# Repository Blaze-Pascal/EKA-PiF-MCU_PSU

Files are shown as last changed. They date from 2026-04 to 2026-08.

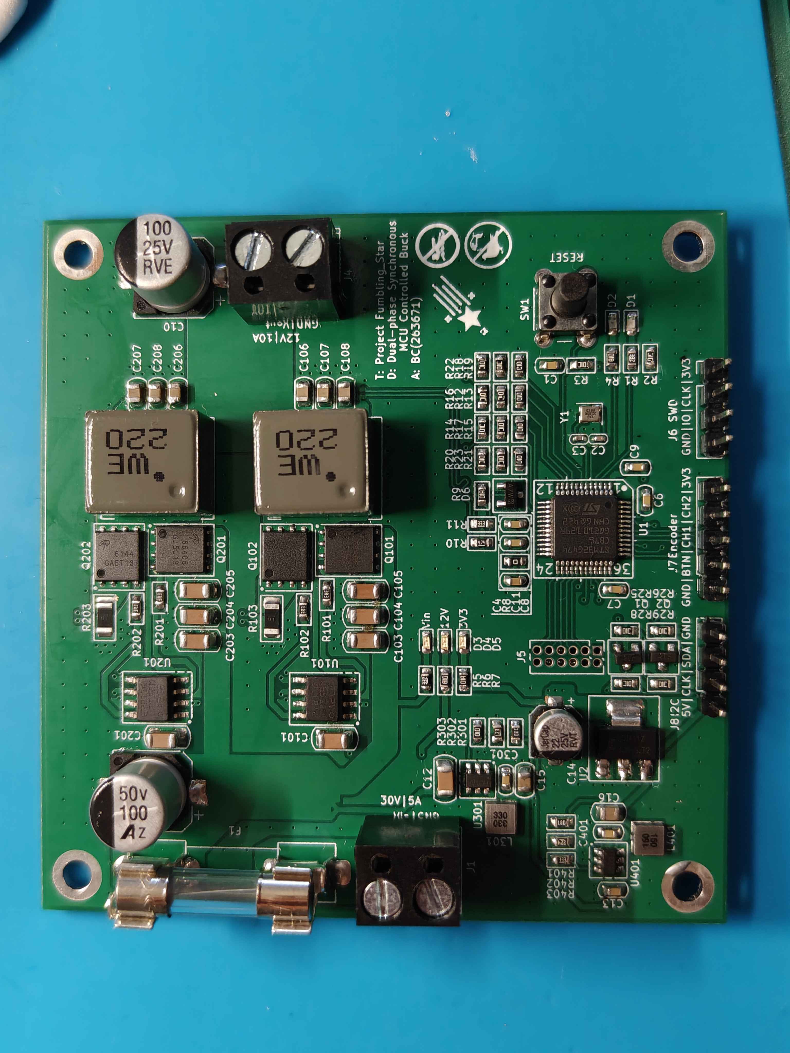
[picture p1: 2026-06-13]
IMG20260607164735.jpg

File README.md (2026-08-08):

# 2-Phase Synchronous Digitally Controlled Buck Converter

Hardware Setup

## Project Overview

**Goal:** Build a multi-phase, MCU-controlled high-power buck converter to act as a current amplifier for a linear lab power supply (30V/5A) at lower voltages.

**Project Scope:**
- **Custom Hardware:** 4-layer power stage and control circuitry designed in KiCad with focus on EMI mitigation. Switching at 250 kHz, designed for 10A at 12V output.
- **Advanced MCU Control:** Firmware written in C (STM32 HAL) for the STM32G474, utilizing a software-defined voltage loop (via FMAC), a pure-hardware current protection loop, and hardware encoder UI integration.

---

## System Architecture

System Schematic Block Diagram

The system is split into two primary domains: the digital control stage, centered around the STM32G474's advanced power-control peripherals, and the power stage, featuring dedicated gate drivers and power MOSFETs.

---

## Hardware Details

### The Power Stage

Power stage

The power stage consists of two identical, interleaved synchronous buck topologies:
- **Gate Drivers:** UCC27211A drivers were selected for their 30V bootstrap tolerance, high 4A peak drive current, and discrete inputs, which allow for precise dead-time insertion directly from the MCU's HRTIM.
- **MOSFETs:** Two different Alpha & Omega DFN-8 MOSFETs are utilized to optimize the specific roles of the buck topology. The AONS66406 is used on the high side for its lower gate charge (faster switching, lower switching losses), while the AON6144 is used on the low side for its lower Rds(on) (better conduction efficiency). 
- **Passives:** The system uses 22µH molded inductors (derated from 8.5A to around 5A). Input capacitance consists of 3x 10µF 50V MLCCs + 100µF electrolytic, while the output utilizes 3x 22µF 25V MLCCs + 100µF electrolytic.

### PCB Layout & EMI Mitigation

PCB Layout Diagram

Great care was taken during the PCB routing phase to minimize radiated and conducted emissions:
- **4-Layer Stackup:** Allows for smaller L1-to-L2 distances, increasing plane coupling and reducing radiated emissions.
- **Strategic Placement:** The MLCC capacitors "hug" the MOSFETs on the input and the inductors on the output to minimize high-frequency current return paths. The slower bulk electrolytic capacitors are placed further out at the input/output terminals.
- **Node Optimization:** The physical copper area of the noisy switching (SW) nodes was kept to an absolute minimum. Molded inductors were chosen specifically to further contain magnetic emissions.
- **Signal Isolation:** Delicate analog feedback signals for the current loops were routed exclusively on the bottom layer to shield them from the noisy power stage on the top layer. They were also routed as differential pairs in order to minimise common mode noise.

### The Digital Stage & UI

Digital stage

The control circuitry relies heavily on the STM32G474's internal mixed-signal capabilities. Additionally, the system features a local user interface: a rotary encoder is connected to a hardware timer in encoder mode, allowing the user to adjust voltage and current setpoints on the fly, which are displayed on an integrated 16x2 LCD.

---

## Control Loop Architecture

<p align="center">
  Voltage loop
  Current loop
</p>

The core of the project is its dual-loop control scheme, leveraging the specific hardware accelerators of the STM32G4 family:

### 1. Software Voltage Control Loop
- **Averaged Sampling:** The High-Resolution Timer (HRTIM) triggers ADC3 to sample the feedback voltage (buffered via an internal OpAmp) at the exact midpoint of the MOSFET's on-time. This effectively averages the signal without requiring software filtering.
- **Hardware Math Acceleration:** The ADC value is sent via DMA directly to the Filter Math Accelerator (FMAC) `WDATA` register, where a Proportional (P) control algorithm is calculated in hardware. 
- **Duty Cycle Update:** Once the FMAC presents the result in the `RDATA` register, it generates an interrupt. The MCU core wakes up, applies corrections for phase current mismatch, and writes the new duty cycle to the HRTIM `CMP1xR` register.

### 2. Hardware Current Control Loop
- **Differential Measurement:** Current is measured via a shunt resistor at the low-side source. The small signal is read differentially for improved noise rejection.
- **Internal Analog Processing:** The voltage is amplified by an internal MCU difference amplifier and immediately fed into a built-in hardware comparator against a threshold set by an internal DAC.
- **Asynchronous Shutdown:** The comparator output is routed directly to the HRTIM external event port. This asynchronous link ensures near-zero latency between an overcurrent event and power stage shutoff, effectively realizing valley current control mode.
- **Blanking Window:** The HRTIM utilizes an internal event blanking window to ignore switching transients, preventing false safety triggers.

---

## Results & Verification

Testing was conducted in progressive stages to ensure system stability and safety:

Test setup

**1. Controller Verification (No Power Stage):** 
Feedback voltages were injected directly into the digital section to validate the software. Interleaving, dead-time insertion, duty cycle adjustment, soft start, current balancing, and overcurrent protection were all verified before high voltage was applied.

**2. Real-World Ripple Testing:** 
With the power stage assembled and hooked to a 25V lab supply, the output voltage ripple was measured at no load.

ripple oscope showcase

The dual-phase interleaved topology yielded a voltage ripple of just 7mVp-p. Compared to single-phase operation (which measured 35mVp-p), interleaving provided an 80% reduction in ripple purely through topology.

**3. Efficiency Analysis:**
The converter was tested across its full operating range using an electronic DC load. 

| Input Volts (V) | Input Current (A) | Output Volts (V) | Output Current (A) | Efficiency (%) |
| :---: | :---: | :---: | :---: | :---: |
| 25.12 | 0.077 | 12.03 | 0.000 | 0.00 |
| 25.12 | 0.218 | 11.91 | 0.299 | 64.82 |
| 24.98 | 0.538 | 11.16 | 0.999 | 82.97 |
| 24.96 | 0.989 | 11.07 | 2.000 | 89.71 |
| 24.90 | 2.110 | 10.92 | 4.500 | 93.60 |
| 24.64 | 3.229 | 10.70 | 7.000 | 94.19 |
| 24.60 | 3.677 | 10.65 | 8.000 | 94.21 |
| 24.56 | 4.573 | 10.55 | 10.000 | 93.95 |

efficiency graph

*Test conditions note: Testing was capped at 25V input (instead of 30V) due to observed ringing at the switching node, which threatened to exceed the transistor voltage ratings.*

---

## Future Improvements

While the current revision serves as a highly successful proof of concept, several areas are targeted for future improvement:

- **Regulator Tuning:** The observed voltage drop under load is due to the implementation of a pure Proportional (P) regulator. A PI regulator caused stability issues in this revision, but with proper parameter tuning, stable operation with minimal offset drop is achievable.
- **Ringing Attenuation:** Adding a snubber circuit or increasing gate resistor values will dampen the switching node ringing. Alternatively, transistors with higher voltage ratings could be used, though at a slight cost to Rds(on) and gate capacitance.
- **Component Optimization:** The passive components and MOSFETs were intentionally over-provisioned for this prototype. A production-ready version would undergo stricter component selection to reduce costs.
- **Software Hardening:** The firmware requires further refinement and exhaustive safety testing to handle edge cases gracefully (e.g., during testing, one phase shut down, and the converter was ultimately saved by the external PSU's overcurrent protection).

---

## Documentation

Comprehensive project documentation is available in the repository (written in Polish, prepared for university coursework in Power Electronics and Digital Signal Controllers):
- **Raport Techniczny:** Initial project considerations and mathematical foundations.
- **Raport Implementacyjny:** Simulated testing and core code fragments.
- **Raport Wdrożeniowy:** Physical implementation and final hardware measurements.
- **Raport Projektowy:** Executive summary of the project lifecycle.

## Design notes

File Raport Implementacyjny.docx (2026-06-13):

Błażej Chodorowski 263671

# Raport Implementacyjny: Oprogramowanie Cyfrowego Sterownika Wielofazowej Przetwornicy Obniżającej

# 1. Wstęp

Celem projektu jest budowa dwufazowej przetwornicy obniżającej napięcie sterowanej w pełni cyfrowo za pomocą mikrokontrolera STM32G4. System realizuje sprzętową, ultraszybką regulację napięcia (Constant Voltage - CV) działającą z częstotliwością 250 kHz oraz sprzętowe ograniczenie prądu (Valley Current Limiting / Constant Current - CC). Dzięki wykorzystaniu akceleratora matematycznego (FMAC), kontrolera DMA oraz zdarzeń sprzętowych (HRTIM External Events), krytyczne pętle sterowania działają niezależnie od głównego rdzenia CPU, pozostawiając zasoby na obsługę interfejsu użytkownika (HMI) oraz funkcji pomocniczych, takich jak programowy Soft-Start czy demokratyczny podział prądów między fazami.

# 2. Architektura Systemu i Sprzętowy Przepływ Danych

Projekt opiera się na dwóch niezależnych pętlach sprzętowych pracujących równolegle:

## 2.1. Główna Pętla Napięciowa (CV - 250 kHz)

Odpowiada za stabilizację napięcia wyjściowego. Przetwarza dane w całości w domenie cyfrowej (format stałoprzecinkowy Q1.15).

## 2.2. Ochronna Pętla Prądowa (Valley Current Limit - CC)

Działa asynchronicznie, z opóźnieniem rzędu ~30-50 ns. Chroni dławiki przed nasyceniem i zapewnia tryb "CC", blokując kolejne cykle kluczowania na podstawie prądu fazy.

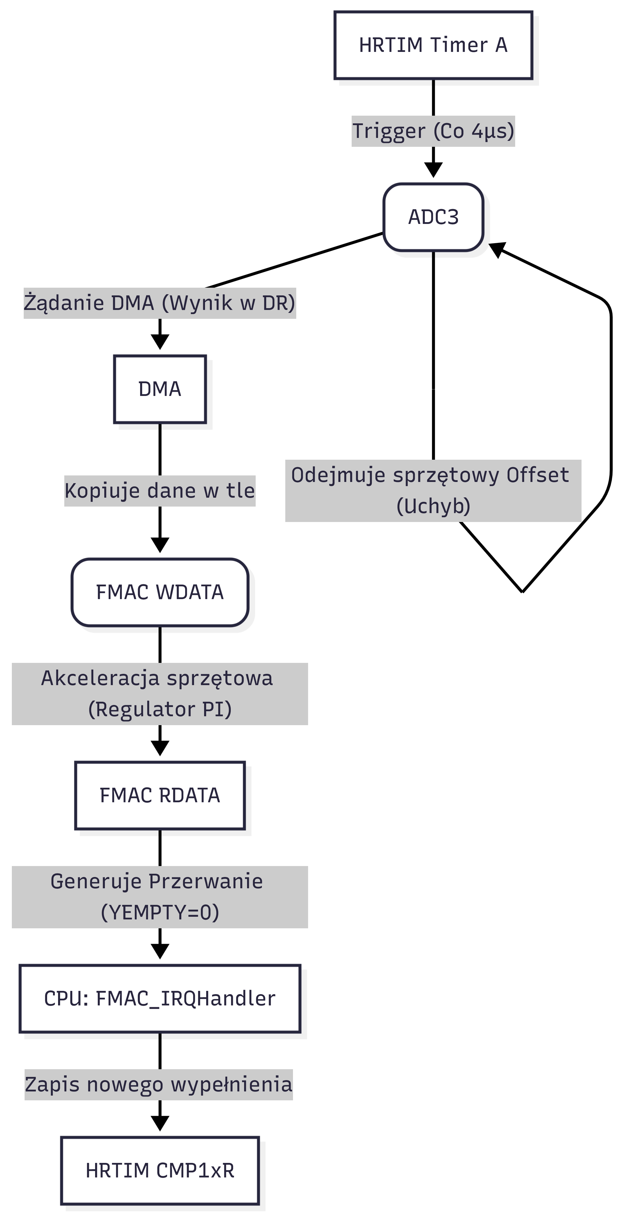
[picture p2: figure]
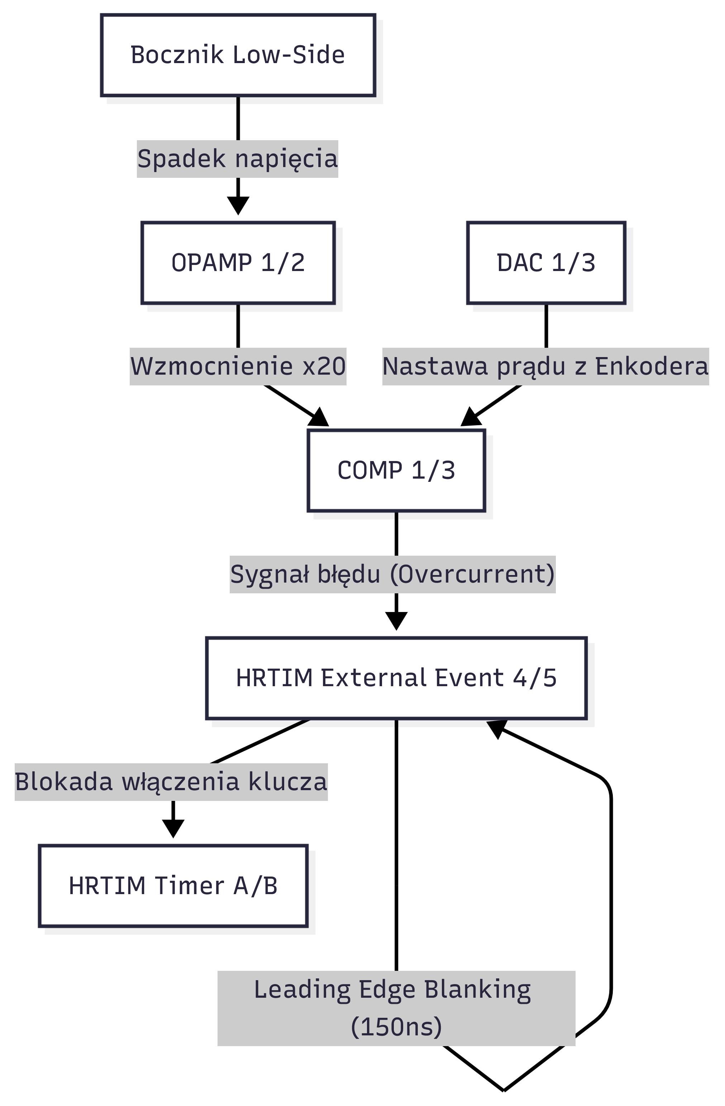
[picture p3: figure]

Rysunek 1 Pętla Napięciowa | Rysunek 2 Pętla Prądowa

# 3. Analiza Kluczowych Modułów Kodu

Poniższe fragmenty kodu ilustrują kluczowe mechanizmy systemu.

## 3.1. Konfiguracja Akceleratora FMAC (Regulator PI)

Akcelerator zastępuje procesor w obliczeniach filtra cyfrowego. Wyliczanie sygnału sterującego odbywa się w pełni sprzętowo.

/* USER CODE BEGIN 2 */

// --- KONFIGURACJA WSPÓŁCZYNNIKÓW FMAC (Regulator PI) ---

FMAC_FilterConfigTypeDef sFmacConfig = {0};

// Wartość 32767 to 1.0 w formacie Q15. Zapewnia idealną pamięć poprzedniego stanu,

// tworząc człon całkujący (I). Dzięki temu uchyb w stanie ustalonym dąży do zera.

int16_t a_coefs[2] = { 32767, 0 };

// Znaki są odwrócone (ujemny b0, dodatni b1), aby zrekompensować ujemne wartości uchybu z ADC

// (kiedy napięcie wyjściowe jest za niskie) i zapewnić ujemne sprzężenie zwrotne pętli.

int16_t b_coefs[3] = { -0x0100, 0x00F0, 0 };

sFmacConfig.pCoeffA = a_coefs;

sFmacConfig.CoeffASize = 2;

sFmacConfig.pCoeffB = b_coefs;

sFmacConfig.CoeffBSize = 3;

// Kanały DMA zasilają FMAC bezpośrednio z ADC, odciążając CPU.

// CPU interweniuje tylko na wyjściu (OutputAccess = IT), aby odebrać gotowy wynik.

sFmacConfig.Filter = FMAC_FUNC_IIR_DIRECT_FORM_1;

sFmacConfig.InputAccess = FMAC_BUFFER_ACCESS_DMA;

sFmacConfig.OutputAccess = FMAC_BUFFER_ACCESS_IT;

HAL_FMAC_FilterConfig(&hfmac, &sFmacConfig);

## 3.2. Obsługa Przerwania FMAC i Current Sharing

Najważniejsza funkcja w systemie. Posiada najwyższy priorytet sprzętowy, stąd zrezygnowano z biblioteki HAL na rzecz bezpośredniego dostępu do rejestrów.

void FMAC_IRQHandler(void)

{

// Weryfikacja gotowości wyniku (YEMPTY zera, oznacza "NIE PUSTY" = gotowy wynik)

if((FMAC->SR & FMAC_SR_YEMPTY) == 0)

{

// Odczyt sprzętowo kasuje żądanie przerwania i odblokowuje pipeline dla kolejnych próbek.

int16_t control_effort_q15 = (int16_t)READ_REG(FMAC->RDATA);

// BEZPIECZNE OKNO AKTUALIZACJI OFFSETU

// Wykonywane tuż po odczycie w czasie przerwania, ponieważ mamy pewność,

// że ADC właśnie zakończyło pomiar i flaga ADSTART = 0.

if (update_offset_flag)

{

ADC3->OFR1 &= ~ADC_OFR1_OFFSET1_EN;

ADC3->OFR1 = (ADC3->OFR1 & ~ADC_OFR1_OFFSET1_Msk) | new_adc_offset;

ADC3->OFR1 |= ADC_OFR1_OFFSET1_EN;

update_offset_flag = 0;

}

// Wyliczenie bazowego wypełnienia z dodaniem limitów nasycenia (Saturacja)

int32_t duty_change = ((int32_t)control_effort_q15 * 21760) >> 15;

int32_t new_ton = pwm_base + duty_change;

if (new_ton < 435) new_ton = 435;

if (new_ton > 10880) new_ton = 10880;

// DEMOKRATYCZNY PODZIAŁ PRĄDU (Average Current Sharing)

// Odczyt ciągły z ADC w locie. Odchyłka w prądach skutkuje nałożeniem delty na fazę 2

// i odjęciem tej samej delty z fazy 1. Dzięki temu całkowita energia układu (suma wypełnień)

// pozostaje stała i główna pętla napięciowa (FMAC) nie traci stabilności.

int32_t current_ph1 = (int32_t)(ADC2->DR);

int32_t current_ph2 = (int32_t)(ADC1->DR);

int32_t balance_effort = (current_ph1 - current_ph2) >> 2; // Proporcjonalny błąd prądu

if (balance_effort > 300) balance_effort = 300;

if (balance_effort < -300) balance_effort = -300;

// Zapis do sprzętowych rejestrów porównawczych z poprawką na prąd faz

HRTIM1->sTimerxRegs[HRTIM_TIMERINDEX_TIMER_A].CMP1xR = new_ton - balance_effort;

HRTIM1->sTimerxRegs[HRTIM_TIMERINDEX_TIMER_B].CMP1xR = (21760 / 2) + new_ton + balance_effort;

// Ucinamy ścieżkę powrotu, nie wchodząc do mało wydajnej obsługi HAL

return;

}

}

## 3.3. Interfejs Użytkownika i Algorytm Soft-Startu

Pętla główna działa asynchronicznie jako system "czasu wolnego" (Low Priority Task). Uniknięto w niej bibliotek blokujących (opóźnień na Systicku), co zapewnia płynność HMI pomimo ogromnej liczby przerwań od akceleratora FMAC w tle.

/* USER CODE BEGIN 3 */

if (HAL_GetTick() - last_update >= 100)

{

last_update = HAL_GetTick();

// 1. ODCZYT ENKODERA (BEZ PRZERWAŃ TIMERA)

// Odczyt sprzętowego licznika zapobiega gubieniu impulsów

int16_t encoder_delta = (int16_t)__HAL_TIM_GET_COUNTER(&htim3);

if (encoder_delta != 0)

{

__HAL_TIM_SET_COUNTER(&htim3, 0);

target_voltage += (float)encoder_delta * 0.1f;

// (Ograniczenia safety: 1.0V do 24.0V)

}

// 2. SOFT-START (Bezpieczna rampa napięcia)

// Zapobiega nasyceniu dławika potężnym prądem inrush, limitując prędkość narastania uchybu w FMAC.

if (current_voltage < target_voltage) {

current_voltage += 0.1f; // +0.1V co 100ms

if (current_voltage > target_voltage) current_voltage = target_voltage;

}

else if (current_voltage > target_voltage) {

current_voltage -= 0.1f;

if (current_voltage < target_voltage) current_voltage = target_voltage;

}

// 3. WYZNACZENIE WARTOŚCI SPRZĘTOWEJ (ADC OFFSET)

// Ograniczenie konwersji zmiennoprzecinkowych zaledwie do jednej iteracji w pętli UI.

float v_pin = current_voltage * (33.0f / 503.0f); // Dzielnik na płytce

uint32_t adc_val = (uint32_t)((v_pin / 2.048f) * 4096.0f);

if (adc_val > 4095) adc_val = 4095;

// Przekazujemy przeliczoną zmienną do wgrania przez bezpieczne okno przerwania.

// Dzięki temu rozwiązujemy problem "Hardware Constraint" zabraniający zapisu do ADSTART=1.

new_adc_offset = adc_val;

update_offset_flag = 1;

// (Kod aktualizujący LCD

}

/* USER CODE END 3 */

# 4. Pomiary weryfikacyjne

W celu weryfikacji poprawności zaimplementowania rozwiązań wykonano szereg pomiarów oscyloskopowych. Ze względu na suboptymalną konstrukcję układu pomiarowego przebiegi wykazują nadmiarowe dzwonienie i przegłos między sygnałami. Zastosowanie poprawnej techniki pomiarowej potwierdziło znaczną redukcję dzwonienia, lecz utrudniało wykonywanie pomiarów.

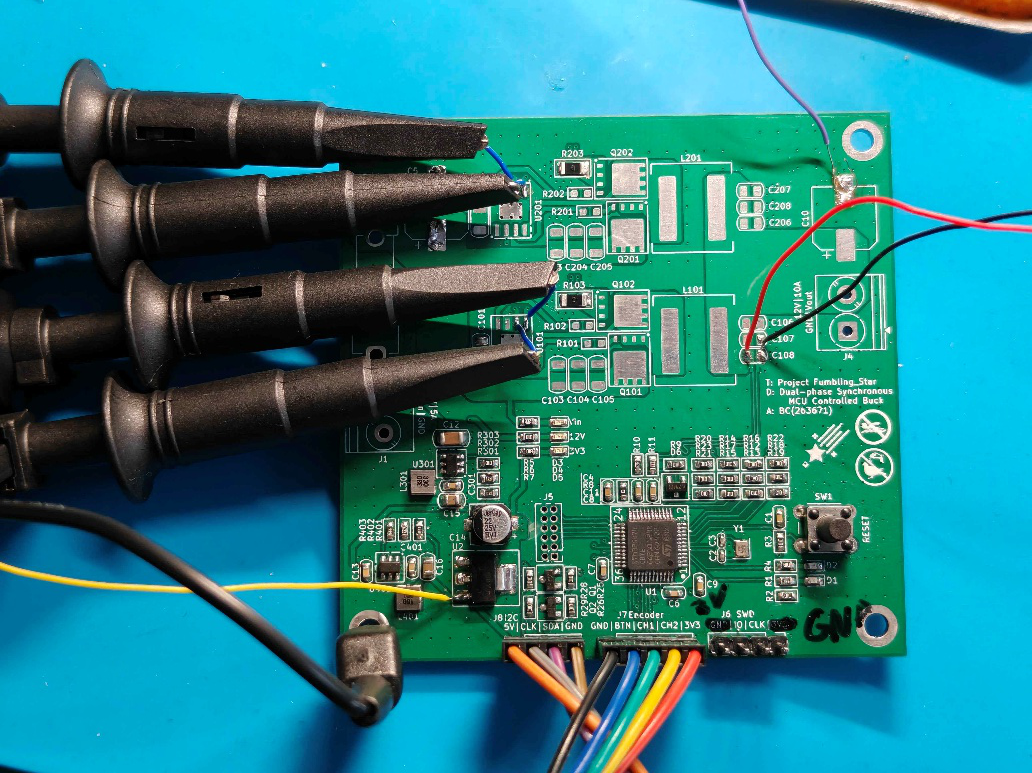
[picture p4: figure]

Rysunek 3 System pomiarowy

## 4.1. Przesunięcie faz

Dokonano pomiarów sygnałów na wyjściach timera HRTIM. Zaobserwowano poprawną nastawę częstotliwości, wypełnienia, przesunięcia fazowego i insercji czasu martwego

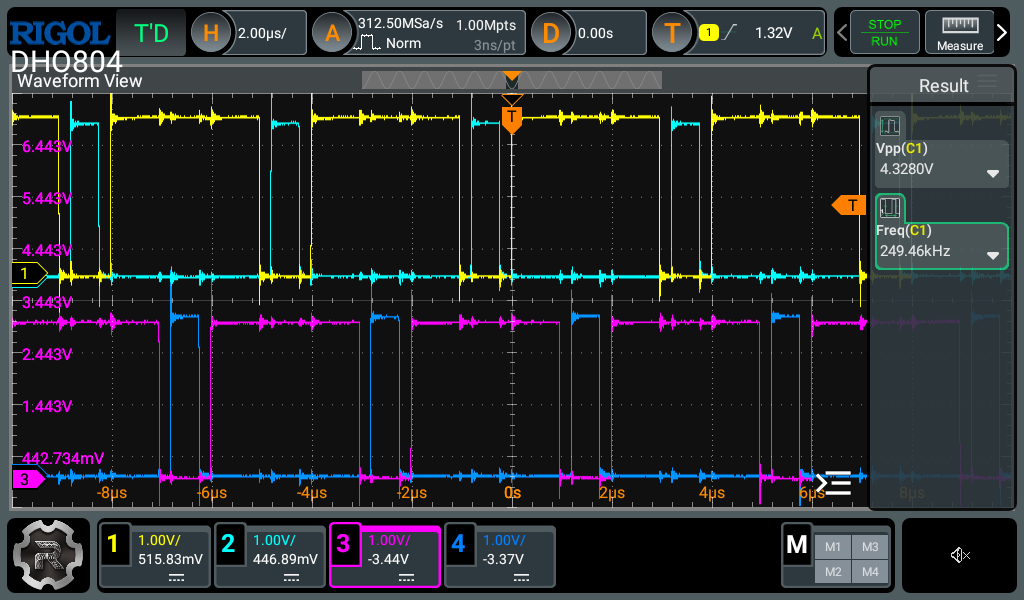
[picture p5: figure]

Rysunek 4 Przebiegi sygnałów na wyjściach HRTIM A i B, weryfikacja przesunięcia fazowego

## 4.2. Czas martwy

Włączono kanały matematyczne wykonujące operację dodawania kanałów dla poszczególnych faz. Zmieniano nastawę programową czasu martwego w celu potwierdzenia poprawnej zmiany i doboru bezpiecznej wartości. Wartość czasu martwego dla kanałów obserwowano poprzez automatyczny pomiar szerokości funkcją -Width. Pomiar zgodny z wyliczeniami dla zegara bloku dead-time w granicach błędu powodowanego dzwonieniem.

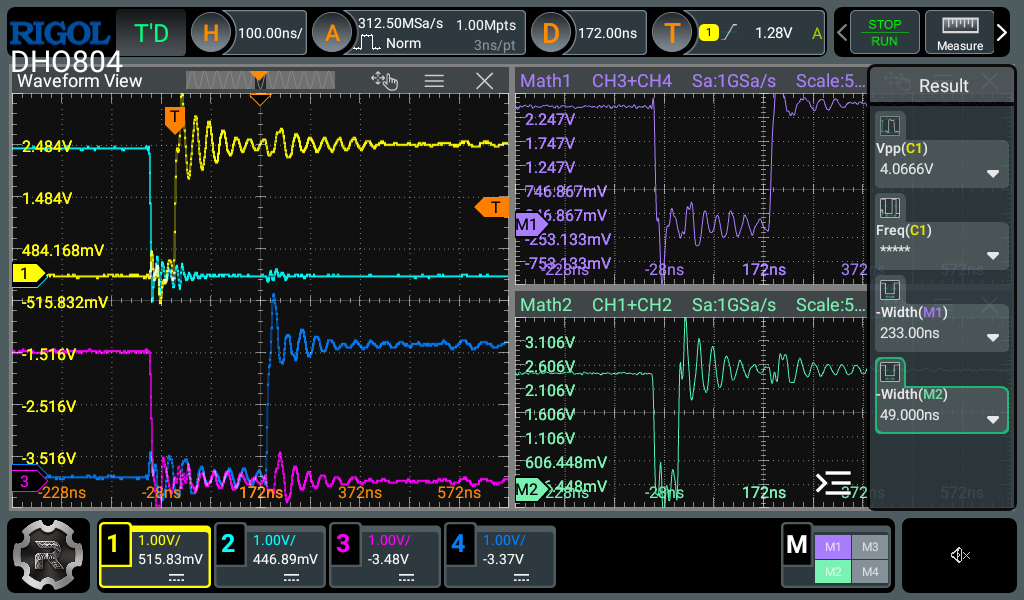
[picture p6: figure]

Rysunek 5 Przebiegi sygnałów na wyjściach HRTIM A i B oraz na kanałach matematycznych, weryfikacja zmiany czasu martwego

## 4.3. Sprzętowe ograniczenie prądowe

Zasilacz laboratoryjny włączono w miejsce pomiaru prądu na boczniku prądowym. Zmieniano nastawę napięcia symulując przepływ prądu przez bocznik zgodnie z zależnością 10mV=1A. Obserwowano zachowanie kanału HRTIM B dla którego symulowano przepływ prądu. Test potwierdził poprawne działanie układu wyłączając klucz górny na czas trwania zdarzenia nadprądowego.

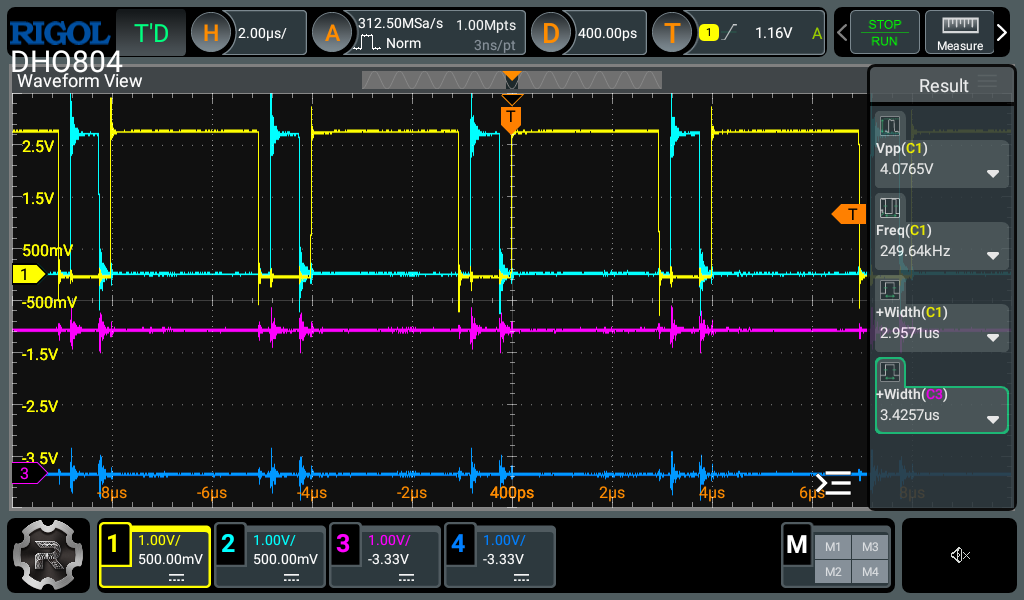
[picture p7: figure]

Rysunek 6 Przebiegi sygnałów na wyjściach HRTIM A i B, kanał B wyłączony przez przekroczenie nastawy prądu

## 4.4. Soft start

Zbadano zachowanie układu podczas rozruchu. W tym celu nastawiono bardzo szeroką podstawę czasu oscyloskopu i mierzono kilka pierwszych sekund startu. Zaobserwowano płynną, liniową zmianę wypełnienia.

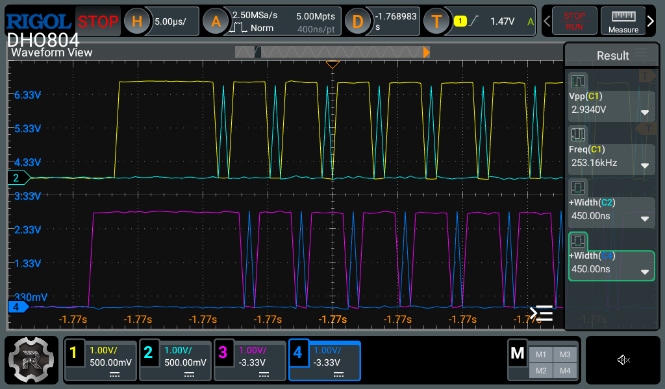
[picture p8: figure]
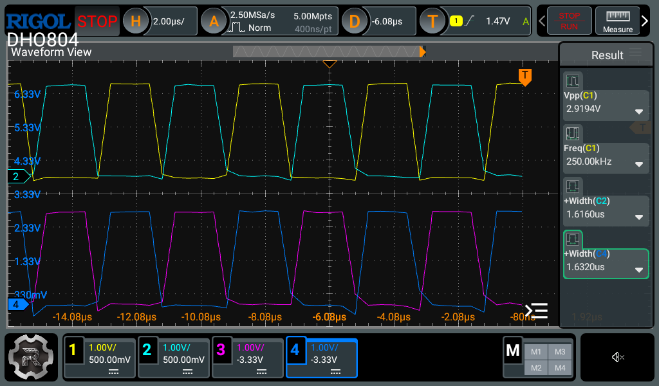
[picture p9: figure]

Rysunek 7 Przebiegi sygnałów na wyjściach HRTIM A i B, moment załączenia HRTIM, wypełnienie minimalne | Rysunek 8 Przebiegi sygnałów na wyjściach HRTIM A i B, około 1,7s później, wypełnienie maksymalne przez odpięte napięciowe sprzężenie zwrotne

## 4.5. Balansowanie prądu faz

Programowo wprowadzono niezbalansowanie prądów faz w celu weryfikacji zmian wypełnienia między fazami. Obserwowano czas załączenia pomiarem +Width dla kanałów 2 i 4 oscyloskopu odpowiadających kluczom high side swoich faz. Zaobserwowano wydłużenie czasu załączenia dla fazy o niższym i skrócenie dla fazy o niższym prądzie.

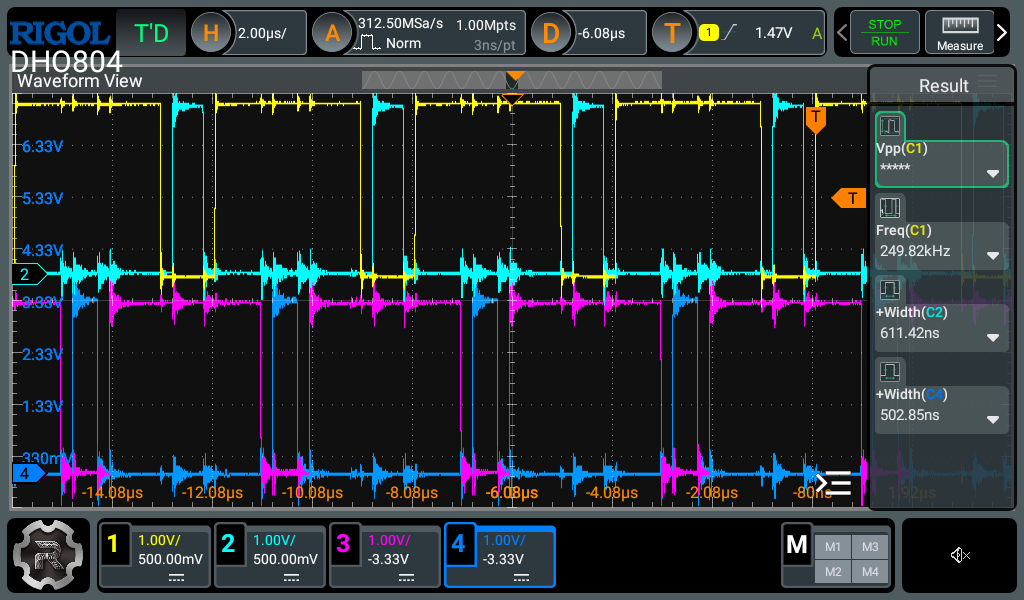
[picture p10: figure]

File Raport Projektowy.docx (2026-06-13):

Błażej Chodorowski 263671

# Raport projektowy

cyfrowo sterowana, Dwufazowa, przetwornica Synchroniczna obniżająca

# 1. Wstęp

Celem projektu było zaprojektowanie, zbudowanie, zaprogramowanie i zbadanie sterowanej cyfrowo dwufazowej przetwornicy synchronicznej obniżającej napięcie. Kluczowe parametry to: napięcie wejściowe 30V, napięcie wyjściowe nastawne, nominalnie 12V, prąd wyjściowy 10A. Projekt oparto na mikrokontrolerze dedykowanym układom mocy STM32G474. Dzięki zastosowaniu zaawansowanych peryferiów takich jak HRTIM i FMAC pełni on rolę cyfrowego kontrolera sygnałów DSC.

# 2. Projekt części sprzętowej

Projekt składa się z głównych bloków hierarchicznych: zasilania pomocniczego, sekcji cyfrowej, dwóch stopni mocy, sekcji feedback. Zdjęcia wnętrz bloków znajdują się w sekcji dodatki.

Sekcje zasilania pomocniczego obniżają napięcie wejściowe w dwóch krokach: Vin->12V dla sterowników bramek i 12V->5V dla zasilania sekcji cyfrowej. 5V trafia na zasilanie wyświetlacza i LDO obniżające do 3.3V dla sekcji mikrokontrolera.

Sekcja mikrokontrolera zawiera w sobie mikrokontroler wraz z elementami do zasilania i taktowania, rezystory dla wbudowanych wzmacniaczy operacyjnych, konwerter stanów logicznych dla komunikacji z wyświetlaczem, złącza enkodera i wyświetlacza.

Stopień mocy zawiera w sobie sterowniki bramek UCC27211D: maksymalne napięcie boost 120V, prąd sink/source 4A, wejścia sterujące TTL, niezależnie sterowanie HI/LO pozwalające na programowy dead-time insertion. Klucze to Alpha&Omega AON6144 o niższym RDSon i AONS66406 o niższym gate charge. Taki dobór powinien minimalizować straty w przetwornicy buck, w której dolny klucz jest załączony dłużej niż górny. Wartości kondensatorów wejściowych, wyjściowych oraz cewek wyliczono ze wzorów podanych w raporcie aplikacyjnym SLVA477B od Texas Instruments. Dodano boczniki mierzące prąd podczas załączenia dolnych kluczy.

Feedback obliczono tak, aby mieścił się w bezpiecznym zakresie dla logiki cyfrowej. Dodatkowo zastosowano ultraszybką diodę zabezpieczającą w celu ochrony przed zbyt wysokim napięciem.

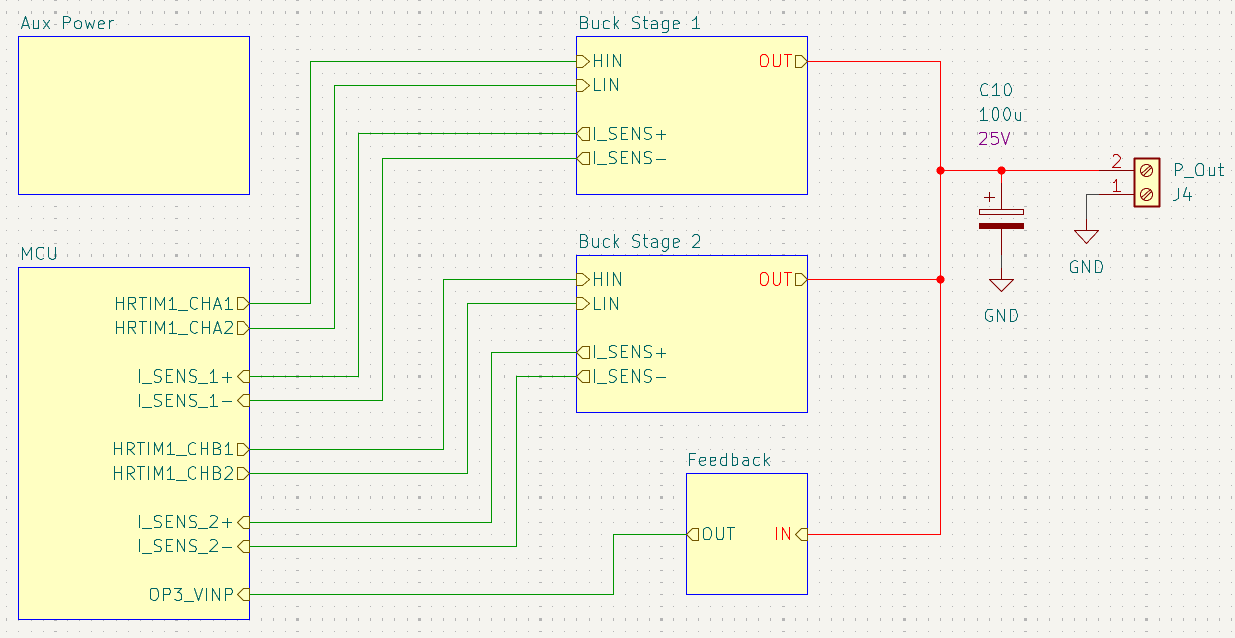
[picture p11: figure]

Rysunek 1 Schemat blokowy części sprzętowej

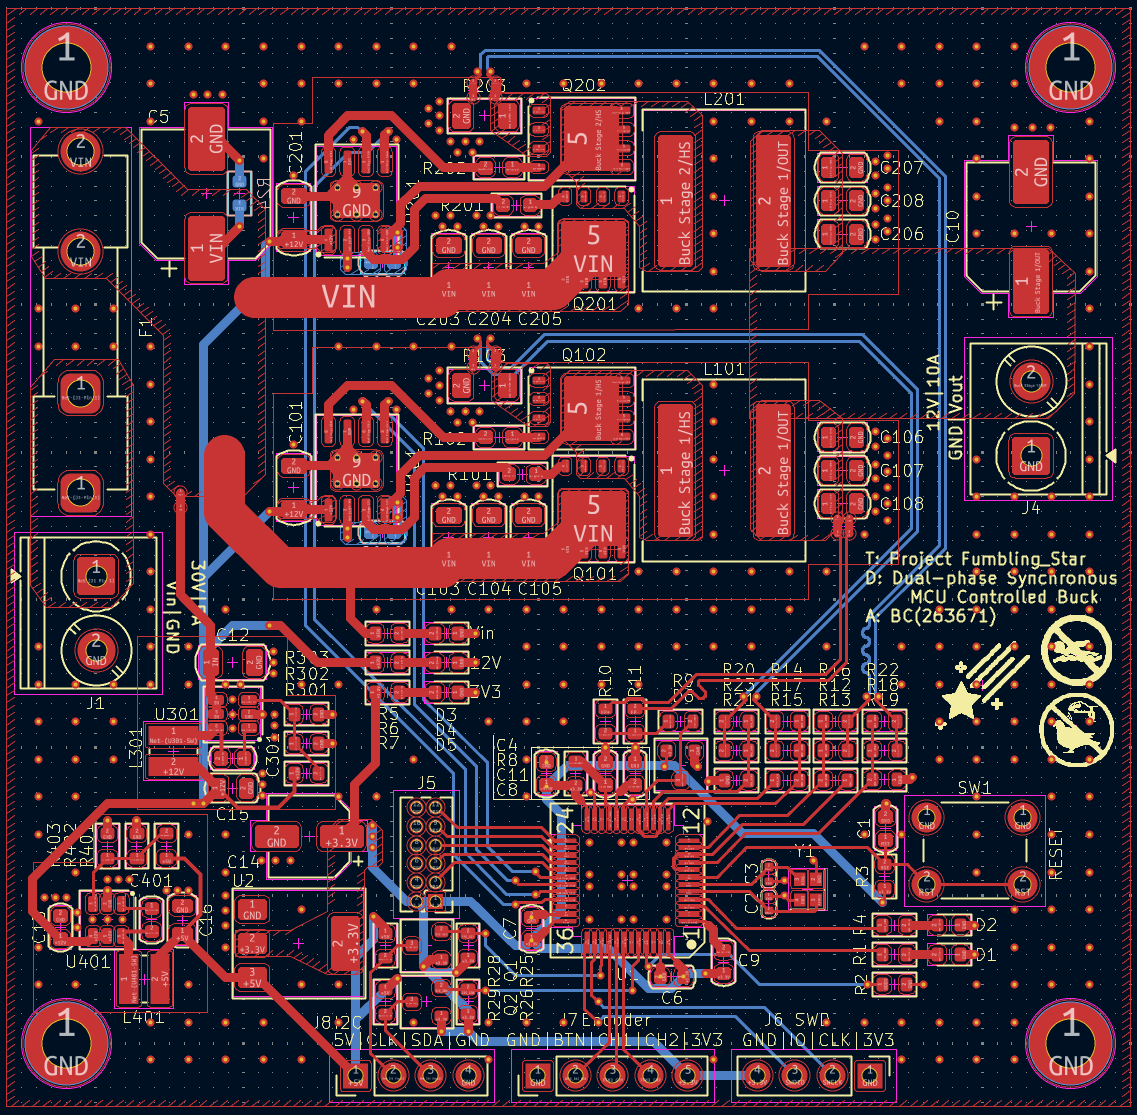
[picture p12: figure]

Rysunek 2 Projekt PCB

# 3. Oprogramowanie mikrokontrolera i peryferia

System wykorzystuje bogatą gammę peryferiów mikrokontrolera STM32G474 do realizacji funkcji DSC. Całość kodu dostępna w repozytorium GitHub projektu: https://github.com/Blaze-Pascal/EKA-PiF-MCU_PSU

Zegar wysokiej rozdzielczości HRTIM służy do sterowania bramkami tranzystorów z częstotliwością 250 kHz. Master Timer generuje przesunięcie fazowe natomiast Timera A i B generują komplementarne przebiegi sterujące. Sprzętowy blok dead-time dodaje czas martwy między kluczami. Dodatkowe poziomy Compare wyzwalają zdarzenia takie jak próbkowanie ADC w połowie załączenia klucza, aby naturalnie uzyskać wartość średnią i zignorować szpilki powstałe podczas przełączania kluczy.

Pomiar prądu realizowany jest poprzez użycie wbudowanych wzmacniaczy operacyjnych w trybie Standalone. Wyprowadzone na piny MCU wzmacniacze zostały następnie połączone do rezystorów tworząc konfigurację wzmacniaczy różnicowych. Pozwala to na wzmocnienie słabego sygnału z boczników do poziomu ADC. Do pomiaru napięcia wzmacniacz został skonfigurowany jako bufor gwarantując wysoką impedancję przetwornikowi i izolując go od dużych wartości rezystancji dzielnika napięciowego. ADC używa wbudowanego źródła napięcia odniesienia co poprawia jego precyzję.

Wyjście wzmacniaczy sygnału prądowego zostało również połączone na płytce z komparatorami pełniącymi rolę sprzętowego ograniczenia prądowego pozwalającego na Valley Current Control. Wzmocniony sygnał jest porównywany z napięciem odniesienia generowanym przez DAC. Jeżeli wartość prądu przekroczy wartość odniesienia sygnał błędu natychmiast trafia na wejścia External Event HRTIM asynchronicznie rozłączając klucz górny do momentu zmniejszenia prądu wyjściowego. Event ma dodatkowo założony Blanking powodujący zignorowanie sygnałów z komparatorów w momencie przełączania kluczy, gdzie może dojść do wystąpienia szpilek prądowych i zarejestrowania zdarzenia false positive.

Pomiar z feedbacku napięciowego trafia na ADC. Po konwersji wartość jest odbierana przez DMA i wysyłana do FMAC – koprocesora matematycznego stworzonego i zoptymalizowanego do liczenia filtrów. Tam zaimplementowano kontroler P obliczający nową wartość wypełnienia dla HRTIM. Wartość jest przekazywana do CPU przez wygenerowanie przerwania i jest następnie dopasowywana do pożądanego zakresu wypełnień (dla poprawnego działania bootstrapu nie można dopuścić do nastawy 100% wypełnienia). Dodatkowo realizowana jest funkcja phase balancing wyrównująca prądy faz na podstawie pomiarów prądu z innych ADC. Po wykonaniu obliczeń, CPU aktualizuje wartości w rejestrach compare HRTIM zmieniając odpowiednia wypełnienie.

Interfejs użytkownika obejmuje wyświetlacz 16x2 sterowany po I2C pokazujący nastawy napięcia i prądu oraz z enkodera połączonego do timera ogólnego przeznaczenia skonfigurowanego w trybie enkodera co zapobiega gubieniu kroków przez enkoder i ogranicza ilość przerwań, które musi obsłużyć procesor.

Zaimplementowano prosty algorytm soft-start, który generuje liniową rampę napięcia zadanego przy starcie przetwornicy. Pętla sprzężenia zwrotnego płynnie podąża za tą wartością, co zapobiega nasyceniu dławików i ogranicza prąd rozruchowy.


Rysunek 3 Pętla napięciowa | Rysunek 4 Pętla prądowa


Rysunek 5 Przebiegi sygnałów na wyjściach HRTIM A i B, weryfikacja przesunięcia fazowego

# 4. Uruchomienie i pomiary

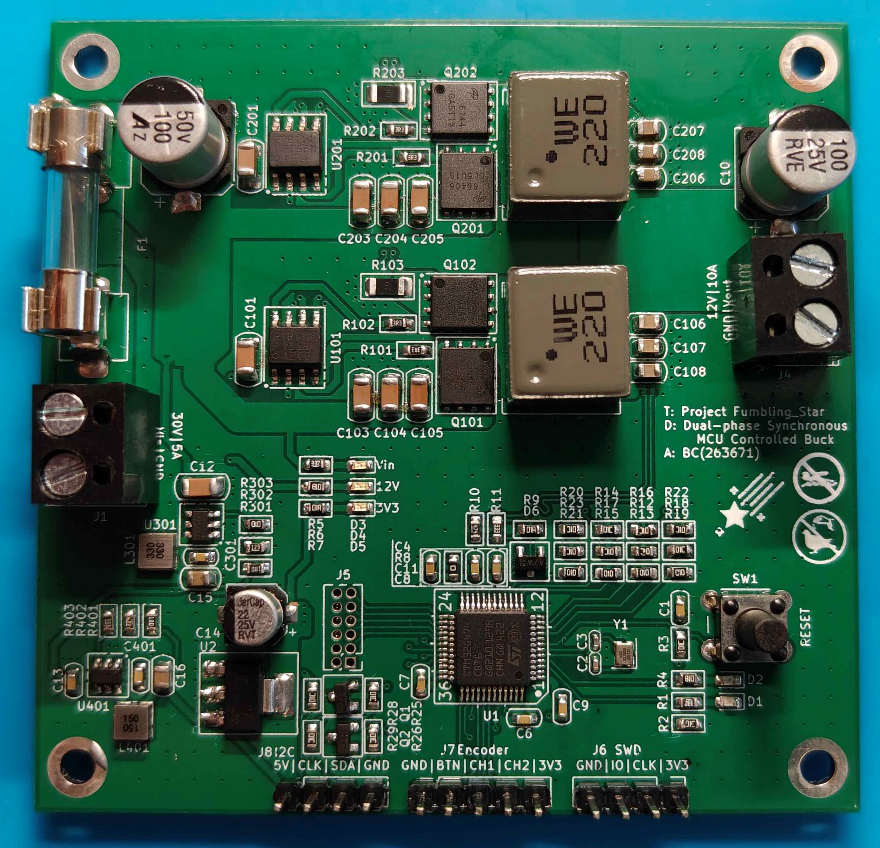
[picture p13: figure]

Rysunek 6 Zbudowany układ

## 4.1. Interleaving i tętnienia wyjściowe

Jedną z zalet konstrukcji wielofazowych jest redukcja tętnień napięcia wyjściowego. Pomiary przeprowadzono sondą oscyloskopową na terminalu wyjściowym stosując sprężynę, aby zminimalizować zakłócenia elektromagnetyczne z otoczenia. Badano amplitudę zakłóceń dla różnych konfiguracji. Pasmo oscyloskopu ograniczone do 20 MHz zgodnie z metodologią pomiaru tętnień zasilaczy.

### 4.1.1. Praca jednofazowa (sonda 10:1, pasmo 20MHz):

Pomiar wykonany bez obciążenia. Tętnienia zmierzone na poziomie ok. 35 mVp-p. Częstotliwość równa częstotliwości pojedynczej fazy: 250 kHz.

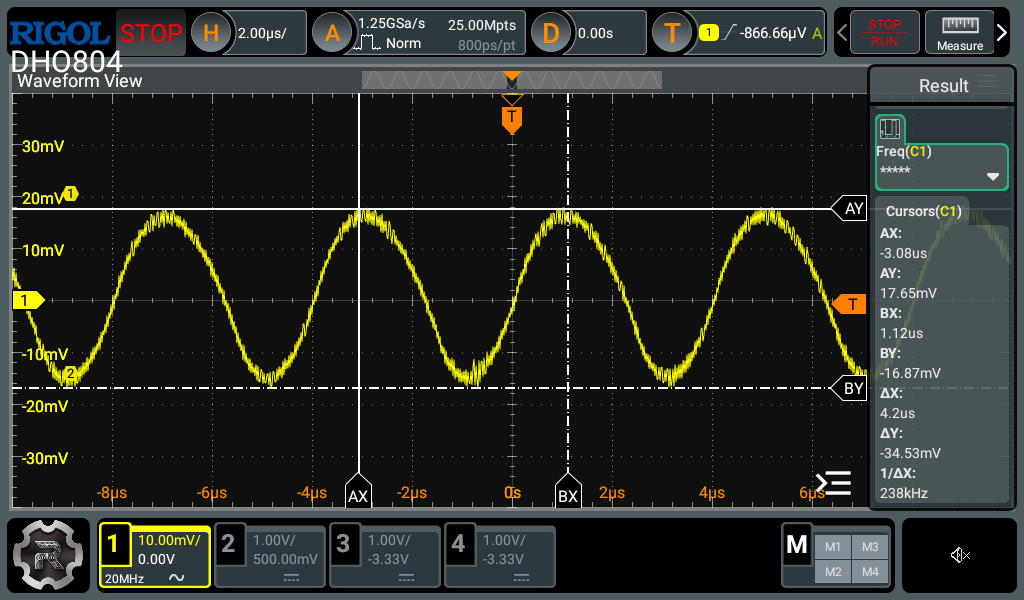
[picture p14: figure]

Rysunek 7 Pomiar tętnień, jedna faza, bez obciążenia

### 4.1.2. Praca dwufazowa z przesunięciem 180° (sonda 1:1, pasmo 20MHz):

Pomiar wykonany bez obciążenia. Tętnienia zmierzone na poziomie ok. 7 mVp-p. Częstotliwość równa częstotliwości dwóch faz: 500 kHz.

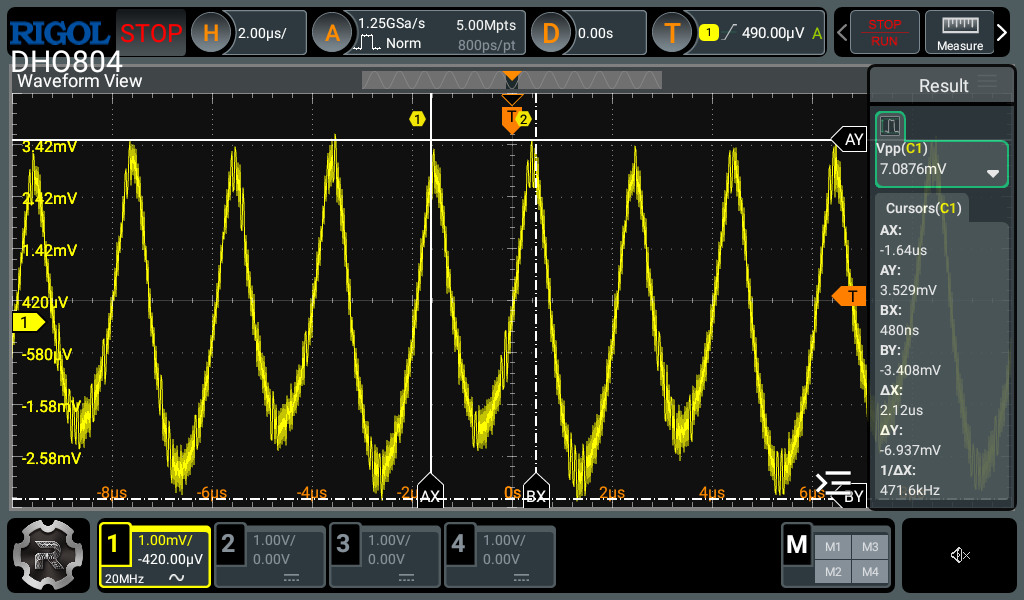
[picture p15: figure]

Rysunek 8 Pomiar tętnień, dwie fazy, bez obciążenia

### 4.1.3. Obciążenie 5A, układ dwufazowy (sonda 1:1, pasmo 20MHz):

Pomiar wykonany przy obciążeniu 5A. Tętnienia bazowe na poziomie 6mVpp (widoczne sporadyczne pakiety szumów otoczenia/zasilacza).

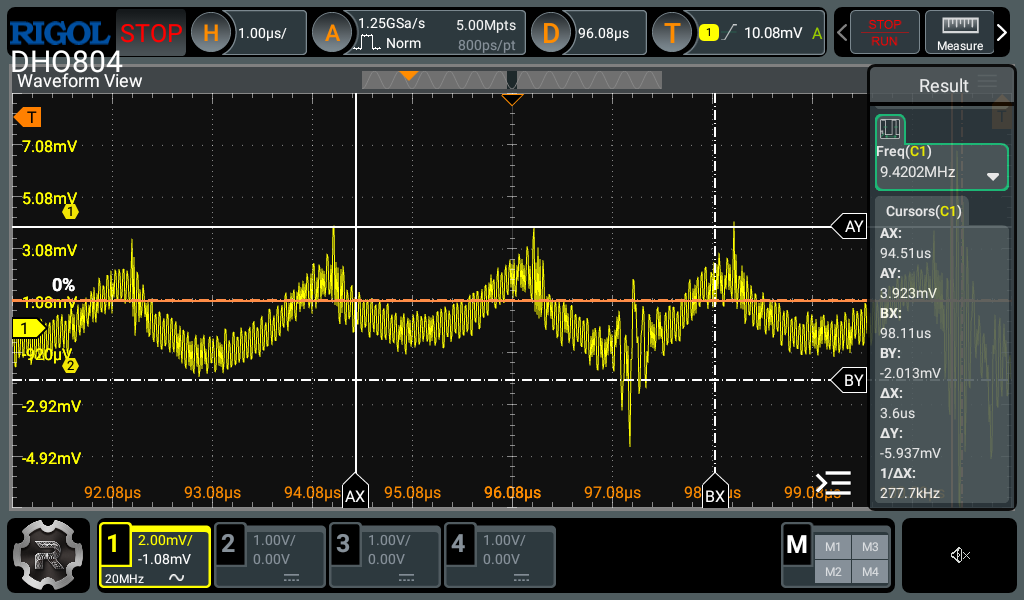
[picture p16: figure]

Rysunek 9 Pomiar tętnień, dwie fazy, obciążenie 5A

Przesunięcie fazowe udowadnia swoją skuteczność. Prądy dławików w węźle sumującym skutecznie znoszą się nawzajem, obniżając amplitudę tętnień napięcia o blisko 80% i podwajając ich częstotliwość, co znacząco odciąża pojemności wyjściowe.

## 4.2. Sprawność energetyczna i odpowiedź pętli sterowania

Zebrano charakterystykę sprawności przetwornicy w zakresie obciążeń od 0A do 10A. W testowanej rewizji oprogramowania aktywny był wyłącznie człon proporcjonalny (P) regulatora.

Tabela 1 Wyniki pomiarów sprawności

Brymen bm2257 | Keysight 34465A [10A] | BKPrecision 8601 | BKPrecision 8601
Uin [V] | Iin [A] | Uout [A] | Iout [A] | n [%]
25.12 | 0.07750 | 12.0301 | 0.000 | 0.00
25.16 | 0.12420 | 11.9954 | 0.099 | 38.00
25.12 | 0.17166 | 11.9501 | 0.199 | 55.15
25.12 | 0.21874 | 11.9122 | 0.299 | 64.82
25.14 | 0.26572 | 11.8791 | 0.399 | 70.95
25.16 | 0.31158 | 11.8018 | 0.499 | 75.12
24.98 | 0.42227 | 11.4065 | 0.748 | 80.89
24.98 | 0.53833 | 11.1680 | 0.999 | 82.97
24.97 | 0.76457 | 11.1149 | 1.499 | 87.27
24.96 | 0.98958 | 11.0797 | 2.000 | 89.71
24.96 | 1.21411 | 11.0465 | 2.500 | 91.13
24.94 | 1.43800 | 11.0143 | 2.999 | 92.10
24.92 | 1.66217 | 10.9850 | 3.500 | 92.82
24.91 | 1.88590 | 10.9564 | 3.999 | 93.27
24.90 | 2.11014 | 10.9291 | 4.500 | 93.60
24.88 | 2.33426 | 10.9020 | 5.000 | 93.86
24.86 | 2.78213 | 10.8480 | 6.000 | 94.11
24.64 | 3.22951 | 10.7074 | 7.000 | 94.19
24.60 | 3.67723 | 10.6532 | 8.000 | 94.21
24.58 | 4.12519 | 10.6006 | 9.000 | 94.09
24.56 | 4.57387 | 10.5534 | 10.000 | 93.95

Rysunek 10 Wykres sprawności w zależności od obciążenia

Punkt maksymalnej sprawności rzędu 94.21% określono dla obciążenia 8 A. Zauważalny spadek napięcia wyjściowego (z 12.03V do 10.55V) przy maksymalnym obciążeniu jest objawem pracy samego członu proporcjonalnego. Układ zatrzymuje się w punkcie równowagi, gdzie zwiększony błąd jest niezbędny do wygenerowania wyższego wypełnienia PWM kompensującego fizyczne spadki napięć na rezystancjach pasożytniczych (cewki, klucze, ścieżki). System sprzętowy działa bez zarzutu, a docelowe usztywnienie charakterystyki wyjściowej zostanie zrealizowane poprzez aktywację członu całkującego (współczynniki dla akceleratora FMAC) w rozwojowej wersji oprogramowania.

## 4.3. Charakterystyka przełączania

Zbadano przebiegi sygnału w węźle przełączającym. Dokonano pomiarów zboczy narastających i opadających oraz dzwonienia. Aby zminimalizować wpływ układu pomiarowego na wyniki wykorzystano sondę w trybie 10:1 minimalizując pojemność i maksymalizując pasmo oraz sprężynę minimalizując indukcyjność pasożytniczą.

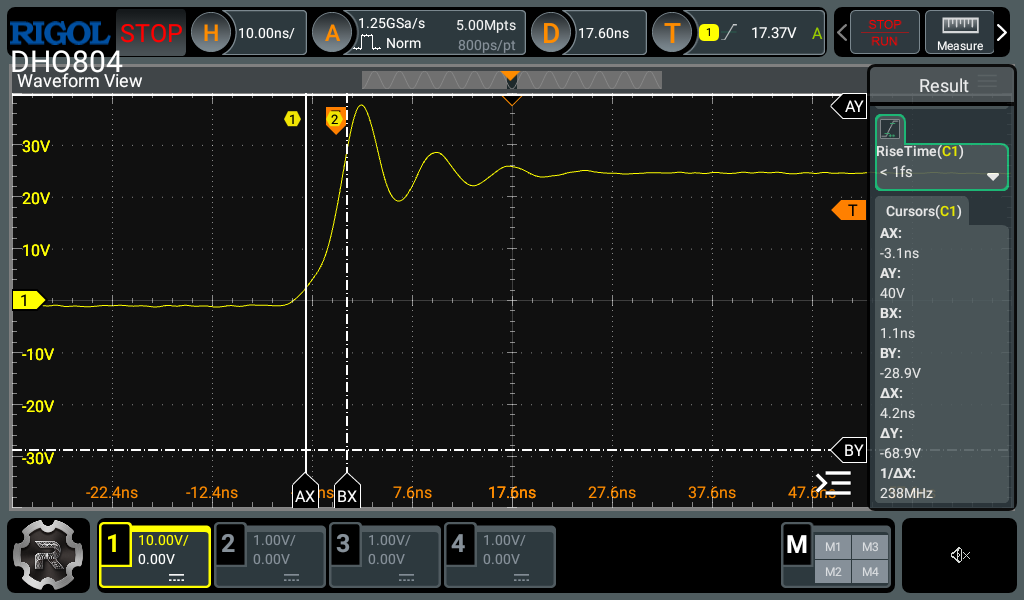
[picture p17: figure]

Rysunek 11 Rysunek 12 Pomiar czasu narastania sygnału SW Node

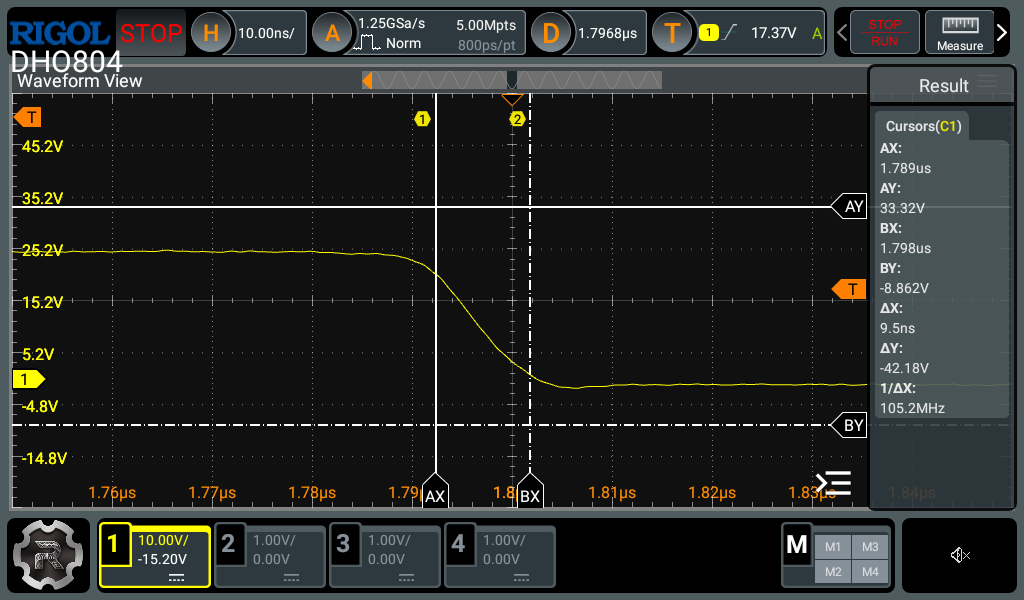
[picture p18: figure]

Rysunek 13 Pomiar czasu opadania sygnału na SW Node

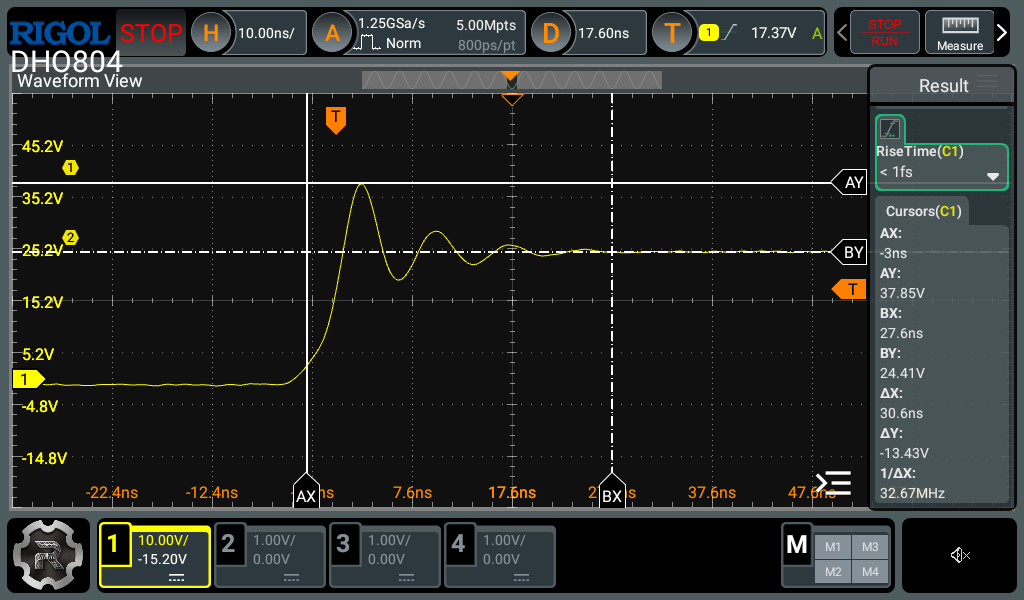
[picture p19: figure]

Rysunek 14 Pomiar amplitudy dzwonienia na zboczy narastającym SW Node

Bardzo krótkie czasy przełączania rzędu Ton 4.2ns i Toff 9.5ns zapewniają bardzo dobrą sprawność. Szybkie czasy przełączania wywołują silne zjawiska falowe. Na zboczu narastającym zaobserwowano dzwonienie (ringing) o amplitudzie sięgającej blisko 12V. Nakładając to na napięcie wejściowe (25V), szczytowe napięcie na tranzystorze wynosi ok. 37V. Z uwagi na to, że klucze posiadają maksymalne dopuszczalne napięcie przebicia na poziomie 40V, układ pracuje z bardzo małym marginesem bezpieczeństwa. Należy przy tym zauważyć, że sygnał o czasie narostu 5 ns oznacza częstotliwość podstawową f = 0.35/tr = 70 MHz. Aby poprawnie zarejestrować taki sygnał wymagane jest pasmo kilkukrotnie większe czego nie gwarantował użyty oscyloskop o paśmie równo 70 MHz.

Sugerowane korekty dla dalszych rewizji:

- Zwiększenie rezystora bramkowego (Rg): Zamiana obecnego rezystora 3.3 oma na wartość wyższą (np. 10 omów) pozwoli łagodniej przeładowywać bramkę, redukując wartość dV/dt, a co za tym idzie drastycznie tłumiąc amplitudę rezonansów pasożytniczych (kosztem spadku sprawności).
- Redukcja czasu martwego (Dead Time): Obecnie nastawione programowo opóźnienie wynosi 220 ns (5 cykli zegara wysokiej rozdzielczości). Z uwagi na wykazane powyżej realne czasy przełączania rzędu ~10 ns, czas ten jest nadmiarowy. Zostanie on zredukowany do bezpiecznych widełek 100 ns – 120 ns, co uwzględnia asymetrię opóźnień propagacji w sterownikach, niweluje ryzyko prądów skrośnych (shoot-through), a jednocześnie redukuje straty na diodach pasożytniczych dolnych tranzystorów.

# 5. Podsumowanie

Projekt sprzętowy wymagał pewnych korekt połączeń: zamiany polaryzacji sygnałów różnicowych pomiaru prądu. Należy poprawić sposób połączenia do footprintu bocznika pomiarowego oraz zastosować połączenie termiczne do masy, aby zredukować ryzyko wystąpienia zjawiska Seebacka. Należy rozważyć zwiększenie wartości rezystorów bramkowych, dodanie układu snubbera lub zastąpienia kluczy wariantami o większym napięciu maksymalnym, aby zminimalizować ryzyko przebicia i umożliwić pracę przy pełnym napięciu.

Projekt programowy skorzystałby na rezygnacji z wykorzystania biblioteki HAL i podejściu bare-metal. Naturalnym krokiem rozwojowym jest implementacja oraz strojenie regulatora PI. Należy dokładniej zwalidować działanie zabezpieczeń oraz dokonać kalibracji odczytów ADC. Należy dokonać korekt w nastawach czasów martwych zgodnie z wykonanymi pomiarami.

Przetwornica wykazuje pełną stabilność sprzętową w trybie napięciowym. Topologia wielofazowa spełniła założenia projektowe redukując tętnienia na wyjściu o ok 80% względem konfiguracji jednofazowej. Rekordowy odczyt sprawności na poziomie 94% przy 8A dowodzi poprawności dobranych elementów mocy.

# 6. Dodatki

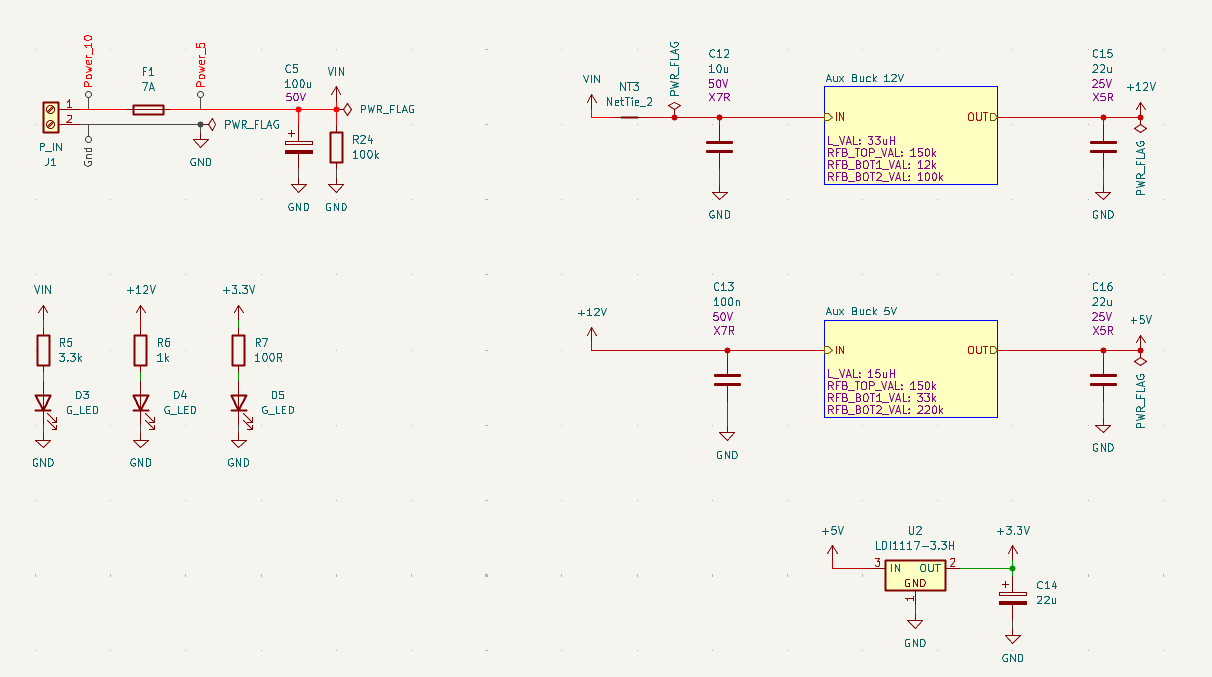
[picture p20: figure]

Rysunek 15 Sekcja zasilania pomocniczego

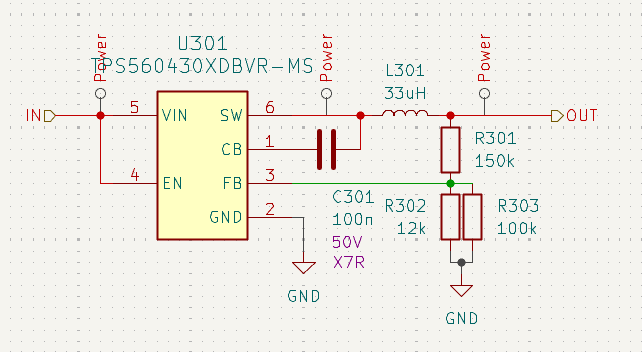
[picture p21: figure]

Rysunek 16 Pomocnicza przetwornica obniżająca

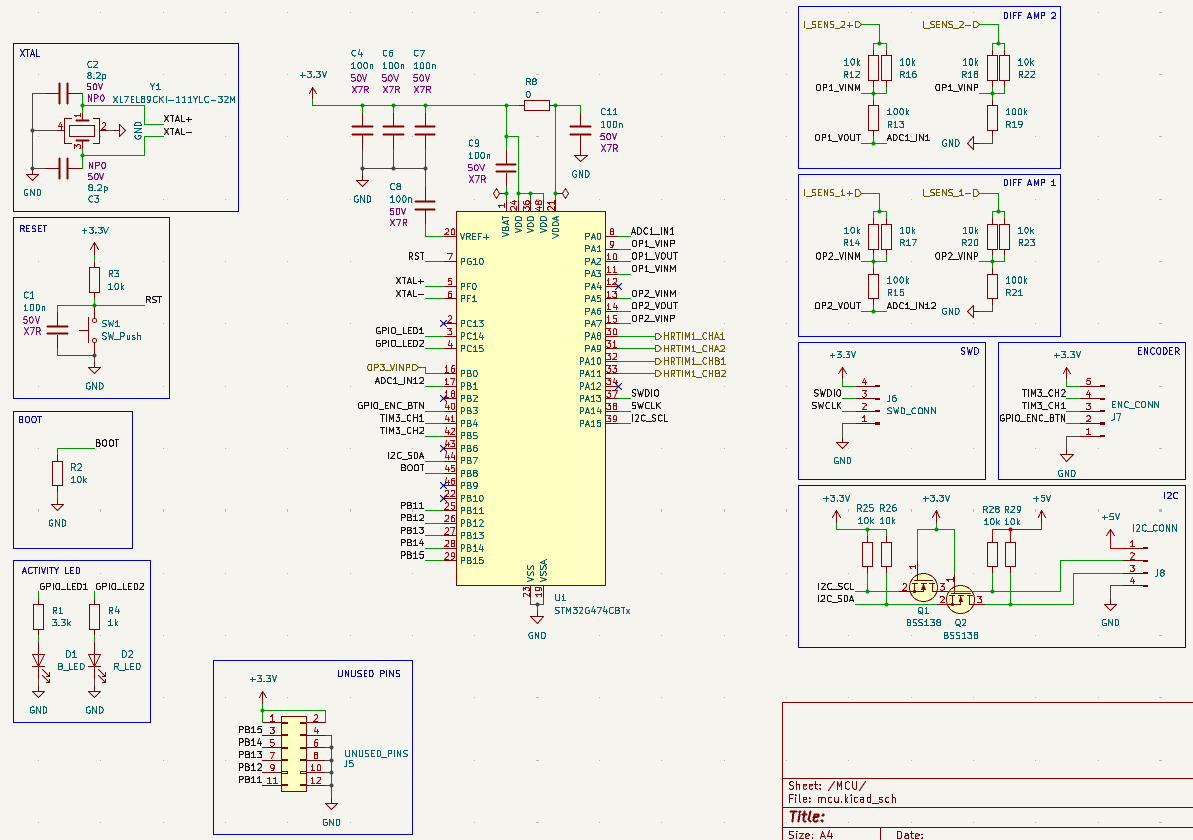
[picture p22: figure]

Rysunek 17 Sekcja cyfrowa

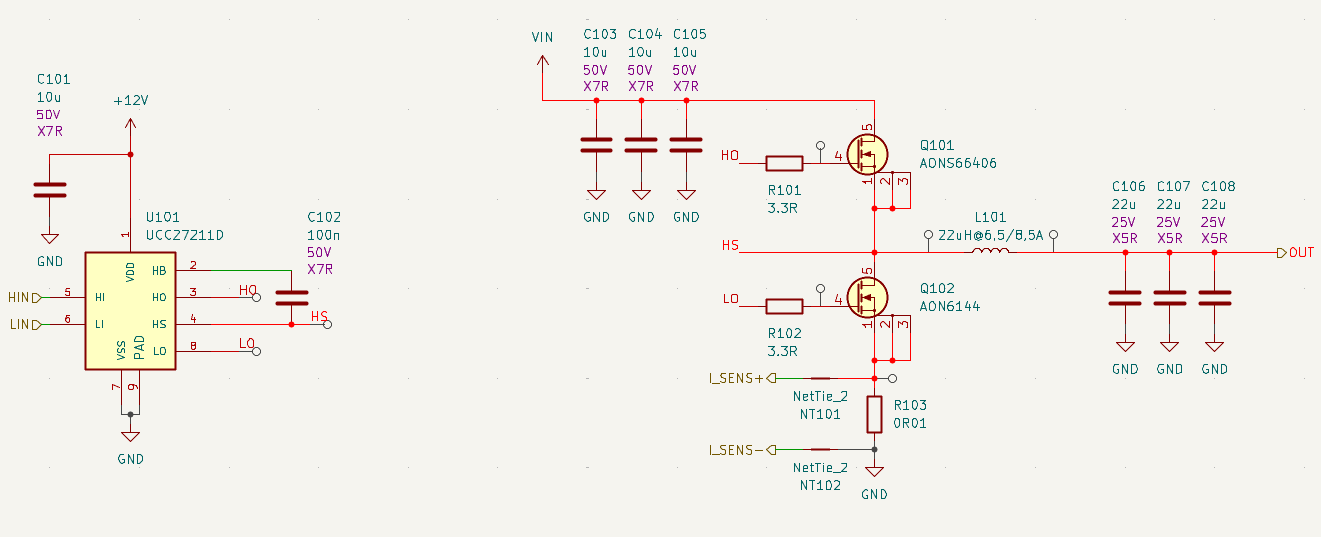
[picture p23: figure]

Rysunek 18 Stopień mocy

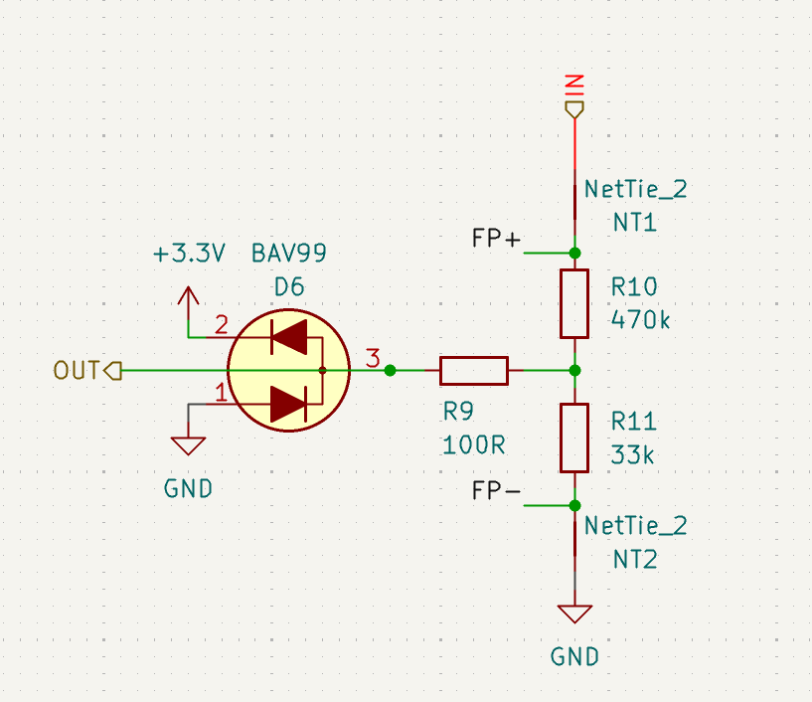
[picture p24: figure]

Rysunek 19 Sekcja feedback

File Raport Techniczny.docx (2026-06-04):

# Raport Techniczny: Architektura Cyfrowego Sterownika Wielofazowej Przetwornicy Obniżającej (Buck)

# 1. Wstęp

Celem niniejszego opracowania jest przedstawienie architektury systemu sterowania dwufazową, synchroniczną przetwornicą DC/DC typu buck. Projekt bazuje na zaawansowanym mikrokontrolerze z serii Mixed-Signal – STM32G474, który dzięki zintegrowanym peryferiom analogowym oraz jednostce wspomagającej przetwarzanie sygnałów (FMAC), pełni rolę cyfrowego kontrolera sygnałowego (DSC).

# 2. Kluczowe Parametry Pracy Układu

- Napięcie wejściowe: 30 V
- Napięcie wyjściowe: 12 V (nastawne)
- Prąd wyjściowy: 10 A (znamionowy)
- Częstotliwość przełączania:
- ≥ 250 kHz na fazę
- Topologia: Dwufazowa, synchroniczna (interleaved)

# 3. Wykorzystanie Peryferiów Układu DSC (STM32G474)

## 3.1. Jednostka HRTIM (High-Resolution Timer)

Sercem układu generowania sygnałów PWM jest timer wysokiej rozdzielczości (HRTIM). Umożliwia on sterowanie kluczami z rozdzielczością czasową rzędu 184 ps, co jest kluczowe dla minimalizacji tętnień napięcia przy wysokich częstotliwościach przełączania.

- Tryb Interleaved: HRTIM generuje dwa przebiegi PWM przesunięte w fazie o 180°, co pozwala na redukcję tętnień prądu wyjściowego oraz zmniejszenie obciążenia kondensatorów wejściowych.
- Dead-time Management: Automatyczne wstawianie czasów martwych dla sterowników UCC27211A w celu uniknięcia prądów skrośnych w gałęziach synchronicznych.

## 3.2. Tor Pomiarowy i Front-End Analogowy (AFE)

Układ wykorzystuje wbudowane wzmacniacze operacyjne oraz komparatory, co eliminuje potrzebę stosowania zewnętrznych układów kondycjonowania sygnałów.

- Pomiar Prądu (Low-Side): Prąd mierzony jest za pomocą rezystorów bocznikujących umieszczonych w źródłach dolnych tranzystorów (AONS66406). Sygnał różnicowy trafia na wejścia wbudowanych wzmacniaczy operacyjnych (OPAMP1/2) pracujących w konfiguracji różnicowej z zewnętrznym sprzężeniem.
- Pomiar Napięcia: Napięcie wyjściowe podawane jest na wzmacniacz pracujący w trybie PGA (Programmable Gain Amplifier), co optymalizuje zakres dynamiczny przetwornika ADC.
- Zabezpieczenie Cycle-by-Cycle: Wyjścia wzmacniaczy prądowych są wewnętrznie połączone z wejściami szybkich komparatorów (COMP), które porównują sygnał z progiem zadanym przez przetworniki DAC. Przekroczenie progu powoduje natychmiastowe (sprzętowe) wyłączenie sygnału PWM w HRTIM.

## 3.3. Przetwarzanie Sygnałów i Pętla Sprzężenia (FMAC & ADC)

W celu odciążenia rdzenia Cortex-M4F, proces obliczeniowy filtracji cyfrowej i algorytmu regulacji zostaje przeniesiony do dedykowanych jednostek:

- ADC (Analog-to-Digital Converter): Próbkowanie prądu i napięcia jest wyzwalane sprzętowo przez HRTIM (dokładnie w momentach środka cyklu PWM lub końca przewodzenia dolnego klucza).
- FMAC (Filter Mathematical Accelerator): Jednostka ta wykonuje obliczenia filtrów cyfrowych (np. IIR dla pętli napięciowej/prądowej). Dane z ADC są przesyłane do FMAC za pomocą kontrolera DMA.
- DMA (Direct Memory Access): Implementacja zakłada przepływ danych: ADC → FMAC → HRTIM (Duty Cycle Update) bez udziału procesora w głównej pętli regulacji. Procesor pozostaje w stanie niskiego poboru mocy lub zajmuje się obsługą interfejsu użytkownika (UI).

# 4. Strategia Sterowania (Control Strategy)

## 4.1. Tryb Napięciowy (Voltage Mode Control) – Plan Minimum

W pierwszej fazie zaimplementowany zostanie cyfrowy regulator PID (lub 2p2z) realizowany przez FMAC, stabilizujący napięcie wyjściowe na podstawie odczytu z ADC.

## 4.2. Tryb Prądowy (Valley/Average Current Control) – Plan Docelowy

Ze względu na umieszczenie boczników po stronie "Low-Side", klasyczny Peak Current Mode Control (PCMC) jest trudny do realizacji (brak informacji o prądzie podczas przewodzenia górnego klucza). Przewiduje się implementację:

- Valley Current Control: Stabilizacja prądu w momencie jego najniższej wartości (tuż przed wyłączeniem dolnego klucza).
- Average Current Mode Control: Wykorzystanie FMAC do uśrednienia pomiarów prądu z boczników dolnych i regulacja prądu średniego dławika, co jest metodą bardziej odporną na szumy przełączania i idealnie wpisuje się w możliwości STM32G4.

# 5. Interfejs Użytkownika i Diagnostyka

Do nastawy parametrów (napięcie/prąd) służy enkoder inkrementalny obsługiwany przez timer w trybie Encoder. Informacje o stanie pracy wyświetlane są na ekranie LCD 16x2 za pośrednictwem magistrali I2C.

# 6. Schemat blokowy

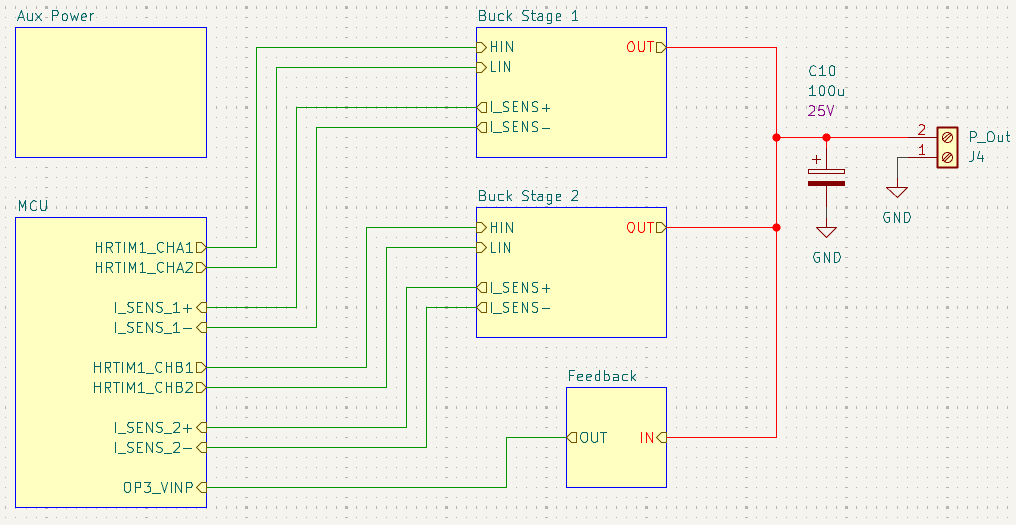
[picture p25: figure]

# 7. Sekcja Mikrokontrolera


# 8. Sekcja przetwornicy


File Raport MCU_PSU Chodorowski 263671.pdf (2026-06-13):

BŁAŻEJ CHODOROWSKI 263671

# RAPORT PROJEKTOWY

CYFROWO STEROWANA, DWUFAZOWA, PRZETWORNICA SYNCHRONICZNA OBNIŻAJĄCA

1. WSTĘP

Celem projektu było zaprojektowanie, zbudowanie, zaprogramowanie i zbadanie sterowanej cyfrowo dwufazowej przetwornicy synchronicznej obniżającej napięcie. Kluczowe parametry to: napięcie wejściowe 30V, napięcie wyjściowe nastawne, nominalnie 12V, prąd wyjściowy 10A. Projekt oparto na mikrokontrolerze dedykowanym układom mocy STM32G474. Dzięki zastosowaniu zaawansowanych peryferiów takich jak HRTIM i FMAC pełni on rolę cyfrowego kontrolera sygnałów DSC.

2. PROJEKT CZĘŚCI SPRZĘTOWEJ

Projekt składa się z głównych bloków hierarchicznych: zasilania pomocniczego, sekcji cyfrowej, dwóch stopni mocy, sekcji feedback. Zdjęcia wnętrz bloków znajdują się w sekcji dodatki.

Sekcje zasilania pomocniczego obniżają napięcie wejściowe w dwóch krokach: Vin->12V dla sterowników bramek i 12V->5V dla zasilania sekcji cyfrowej. 5V trafia na zasilanie wyświetlacza i LDO obniżające do 3.3V dla sekcji mikrokontrolera.

Sekcja mikrokontrolera zawiera w sobie mikrokontroler wraz z elementami do zasilania i taktowania, rezystory dla wbudowanych wzmacniaczy operacyjnych, konwerter stanów logicznych dla komunikacji z wyświetlaczem, złącza enkodera i wyświetlacza.

Stopień mocy zawiera w sobie sterowniki bramek UCC27211D: maksymalne napięcie boost 120V, prąd sink/source 4A, wejścia sterujące TTL, niezależnie sterowanie HI/LO pozwalające na programowy dead-time insertion. Klucze to Alpha&Omega AON6144 o niższym RDSon i AONS66406 o niższym gate charge. Taki dobór powinien minimalizować straty w przetwornicy buck, w której dolny klucz jest załączony dłużej niż górny. Wartości kondensatorów wejściowych, wyjściowych oraz cewek wyliczono ze wzorów podanych w raporcie aplikacyjnym SLVA477B od Texas Instruments. Dodano boczniki mierzące prąd podczas załączenia dolnych kluczy.

Feedback obliczono tak, aby mieścił się w bezpiecznym zakresie dla logiki cyfrowej. Dodatkowo zastosowano ultraszybką diodę zabezpieczającą w celu ochrony przed zbyt wysokim napięciem.


Rysunek 1 Schemat blokowy części sprzętowej


Rysunek 2 Projekt PCB

3. OPROGRAMOWANIE MIKROKONTROLERA I PERYFERIA

System wykorzystuje bogatą gammę peryferiów mikrokontrolera STM32G474 do realizacji funkcji DSC. Całość kodu dostępna w repozytorium GitHub projektu: https://github.com/Blaze-Pascal/EKA-PiF-MCU_PSU

Zegar wysokiej rozdzielczości HRTIM służy do sterowania bramkami tranzystorów z częstotliwością 250 kHz. Master Timer generuje przesunięcie fazowe natomiast Timera A i B generują komplementarne przebiegi sterujące. Sprzętowy blok dead-time dodaje czas martwy między kluczami. Dodatkowe poziomy Compare wyzwalają zdarzenia takie jak próbkowanie ADC w połowie załączenia klucza, aby naturalnie uzyskać wartość średnią i zignorować szpilki powstałe podczas przełączania kluczy.

Pomiar prądu realizowany jest poprzez użycie wbudowanych wzmacniaczy operacyjnych w trybie Standalone. Wyprowadzone na piny MCU wzmacniacze zostały następnie połączone do rezystorów tworząc konfigurację wzmacniaczy różnicowych. Pozwala to na wzmocnienie słabego sygnału z boczników do poziomu ADC. Do pomiaru napięcia wzmacniacz został skonfigurowany jako bufor gwarantując wysoką impedancję przetwornikowi i izolując go od dużych wartości rezystancji dzielnika napięciowego. ADC używa wbudowanego źródła napięcia odniesienia co poprawia jego precyzję.

Wyjście wzmacniaczy sygnału prądowego zostało również połączone na płytce z komparatorami pełniącymi rolę sprzętowego ograniczenia prądowego pozwalającego na Valley Current Control. Wzmocniony sygnał jest porównywany z napięciem odniesienia generowanym przez DAC. Jeżeli wartość prądu przekroczy wartość odniesienia sygnał błędu natychmiast trafia na wejścia External Event HRTIM asynchronicznie rozłączając klucz górny do momentu zmniejszenia prądu wyjściowego. Event ma dodatkowo założony Blanking powodujący zignorowanie sygnałów z komparatorów w momencie przełączania kluczy, gdzie może dojść do wystąpienia szpilek prądowych i zarejestrowania zdarzenia false positive.

Pomiar z feedbacku napięciowego trafia na ADC. Po konwersji wartość jest odbierana przez DMA i wysyłana do FMAC – koprocesora matematycznego stworzonego i zoptymalizowanego do liczenia filtrów. Tam zaimplementowano kontroler P obliczający nową wartość wypełnienia dla HRTIM. Wartość jest przekazywana do CPU przez wygenerowanie przerwania i jest następnie dopasowywana do pożądanego zakresu wypełnień (dla poprawnego działania bootstrapu nie można dopuścić do nastawy 100% wypełnienia). Dodatkowo realizowana jest funkcja phase balancing wyrównująca prądy faz na podstawie pomiarów prądu z innych ADC. Po wykonaniu obliczeń, CPU aktualizuje wartości w rejestrach compare HRTIM zmieniając odpowiednia wypełnienie.

Interfejs użytkownika obejmuje wyświetlacz 16x2 sterowany po I2C pokazujący nastawy napięcia i prądu oraz z enkodera połączonego do timera ogólnego przeznaczenia skonfigurowanego w trybie enkodera co zapobiega gubieniu kroków przez enkoder i ogranicza ilość przerwań, które musi obsłużyć procesor.

Zaimplementowano prosty algorytm soft-start, który generuje liniową rampę napięcia zadanego przy starcie przetwornicy. Pętla sprzężenia zwrotnego płynnie podąża za tą wartością, co zapobiega nasyceniu dławików i ogranicza prąd rozruchowy.


Rysunek 3 Pętla napięciowa | Rysunek 4 Pętla prądowa


Rysunek 5 Przebiegi sygnałów na wyjściach HRTIM A i B, weryfikacja przesunięcia fazowego

4. URUCHOMIENIE I POMIARY


Rysunek 6 Zbudowany układ

4.1. INTERLEAVING I TĘTNIENIA WYJŚCIOWE

Jedną z zalet konstrukcji wielofazowych jest redukcja tętnień napięcia wyjściowego. Pomiary przeprowadzono sondą oscyloskopową na terminalu wyjściowym stosując sprężynę, aby zminimalizować zakłócenia elektromagnetyczne z otoczenia. Badano amplitudę zakłóceń dla różnych konfiguracji. Pasmo oscyloskopu ograniczone do 20 MHz zgodnie z metodologią pomiaru tętnień zasilaczy.

4.1.1. PRACA JEDNOFAZOWA (SONDA 10:1, PASMO 20MHZ):

Pomiar wykonany bez obciążenia. Tętnienia zmierzone na poziomie ok. 35 mVp-p. Częstotliwość równa częstotliwości pojedynczej fazy: 250 kHz.


Rysunek 7 Pomiar tętnień, jedna faza, bez obciążenia

4.1.2. PRACA DWUFAZOWA Z PRZESUNIĘCIEM 180° (SONDA 1:1, PASMO 20MHZ):

Pomiar wykonany bez obciążenia. Tętnienia zmierzone na poziomie ok. 7 mVp-p. Częstotliwość równa częstotliwości dwóch faz: 500 kHz.


Rysunek 8 Pomiar tętnień, dwie fazy, bez obciążenia

4.1.3. OBCIĄŻENIE 5A, UKŁAD DWUFAZOWY (SONDA 1:1, PASMO 20MHZ):

Pomiar wykonany przy obciążeniu 5A. Tętnienia bazowe na poziomie 6mVpp (widoczne sporadyczne pakiety szumów otoczenia/zasilacza).


Rysunek 9 Pomiar tętnień, dwie fazy, obciążenie 5A

Przesunięcie fazowe udowadnia swoją skuteczność. Prądy dławików w węźle sumującym skutecznie znoszą się nawzajem, obniżając amplitudę tętnień napięcia o blisko 80% i podwajając ich częstotliwość, co znacząco odciąża pojemności wyjściowe.

4.2. SPRAWNOŚĆ ENERGETYCZNA I ODPOWIEDŹ PĘTLI STEROWANIA

Zebrano charakterystykę sprawności przetwornicy w zakresie obciążeń od 0A do 10A. W testowanej rewizji oprogramowania aktywny był wyłącznie człon proporcjonalny (P) regulatora.

Tabela 1 Wyniki pomiarów sprawności

Brymen
bm2257

Keysight
34465A [10A]

BKPrecision
8601

BKPrecision
8601
Uin [V] | Iin [A] | Uout [A] | Iout [A] | n [%]
25.12 | 0.07750 | 12.0301 | 0.000 | 0.00
25.16 | 0.12420 | 11.9954 | 0.099 | 38.00
25.12 | 0.17166 | 11.9501 | 0.199 | 55.15
25.12 | 0.21874 | 11.9122 | 0.299 | 64.82
25.14 | 0.26572 | 11.8791 | 0.399 | 70.95
25.16 | 0.31158 | 11.8018 | 0.499 | 75.12
24.98 | 0.42227 | 11.4065 | 0.748 | 80.89
24.98 | 0.53833 | 11.1680 | 0.999 | 82.97
24.97 | 0.76457 | 11.1149 | 1.499 | 87.27
24.96 | 0.98958 | 11.0797 | 2.000 | 89.71
24.96 | 1.21411 | 11.0465 | 2.500 | 91.13
24.94 | 1.43800 | 11.0143 | 2.999 | 92.10
24.92 | 1.66217 | 10.9850 | 3.500 | 92.82
24.91 | 1.88590 | 10.9564 | 3.999 | 93.27
24.90 | 2.11014 | 10.9291 | 4.500 | 93.60
24.88 | 2.33426 | 10.9020 | 5.000 | 93.86

Sprawność n [%]; Prąd wyjściowy Iout [A]

Rysunek 10 Wykres sprawności w zależności od obciążenia

Punkt maksymalnej sprawności rzędu 94.21% określono dla obciążenia 8 A. Zauważalny spadek napięcia wyjściowego (z 12.03V do 10.55V) przy maksymalnym obciążeniu jest objawem pracy samego członu proporcjonalnego. Układ zatrzymuje się w punkcie równowagi, gdzie zwiększony błąd jest niezbędny do wygenerowania wyższego wypełnienia PWM kompensującego fizyczne spadki napięć na rezystancjach pasożytniczych (cewki, klucze, ścieżki). System sprzętowy działa bez zarzutu, a docelowe usztywnienie charakterystyki wyjściowej zostanie zrealizowane poprzez aktywację członu całkującego (współczynniki dla akceleratora FMAC) w rozwojowej wersji oprogramowania.


4.3. CHARAKTERYSTYKA PRZEŁĄCZANIA

Zbadano przebiegi sygnału w węźle przełączającym. Dokonano pomiarów zboczy narastających i opadających oraz dzwonienia. Aby zminimalizować wpływ układu pomiarowego na wyniki wykorzystano sondę w trybie 10:1 minimalizując pojemność i maksymalizując pasmo oraz sprężynę minimalizując indukcyjność pasożytniczą.

Rysunek 11 Rysunek 12 Pomiar czasu narastania sygnału SW Node

Rysunek 13 Pomiar czasu opadania sygnału na SW Node

Rysunek 14 Pomiar amplitudy dzwonienia na zboczy narastającym SW Node

Bardzo krótkie czasy przełączania rzędu Ton 4.2ns i Toff 9.5ns zapewniają bardzo dobrą sprawność. Szybkie czasy przełączania wywołują silne zjawiska falowe. Na zboczu narastającym zaobserwowano dzwonienie (ringing) o amplitudzie sięgającej blisko 12V. Nakładając to na napięcie wejściowe (25V), szczytowe napięcie na tranzystorze wynosi ok. 37V. Z uwagi na to, że klucze posiadają maksymalne dopuszczalne napięcie przebicia na poziomie 40V, układ pracuje z bardzo małym marginesem bezpieczeństwa. Należy przy tym zauważyć, że sygnał o czasie narostu 5 ns oznacza częstotliwość podstawową f = 0.35/tr = 70 MHz. Aby poprawnie zarejestrować taki sygnał wymagane jest pasmo kilkukrotnie większe czego nie gwarantował użyty oscyloskop o paśmie równo 70 MHz.

Sugerowane korekty dla dalszych rewizji:

- Zwiększenie rezystora bramkowego (Rg): Zamiana obecnego rezystora 3.3 oma na wartość wyższą (np. 10 omów) pozwoli łagodniej przeładowywać bramkę, redukując wartość dV/dt, a co za tym idzie drastycznie tłumiąc amplitudę rezonansów pasożytniczych (kosztem spadku sprawności).
- Redukcja czasu martwego (Dead Time): Obecnie nastawione programowo opóźnienie wynosi 220 ns (5 cykli zegara wysokiej rozdzielczości). Z uwagi na wykazane powyżej realne czasy przełączania rzędu ~10 ns, czas ten jest nadmiarowy. Zostanie on zredukowany do bezpiecznych widełek 100 ns – 120 ns, co uwzględnia asymetrię opóźnień propagacji w sterownikach, niweluje ryzyko prądów skrośnych (shoot-through), a jednocześnie redukuje straty na diodach pasożytniczych dolnych tranzystorów.
5. PODSUMOWANIE

Projekt sprzętowy wymagał pewnych korekt połączeń: zamiany polaryzacji sygnałów różnicowych pomiaru prądu. Należy poprawić sposób połączenia do footprintu bocznika pomiarowego oraz zastosować połączenie termiczne do masy, aby zredukować ryzyko wystąpienia zjawiska Seebacka. Należy rozważyć zwiększenie wartości rezystorów bramkowych, dodanie układu snubbera lub zastąpienia kluczy wariantami o większym napięciu maksymalnym, aby zminimalizować ryzyko przebicia i umożliwić pracę przy pełnym napięciu.

Projekt programowy skorzystałby na rezygnacji z wykorzystania biblioteki HAL i podejściu bare-metal. Naturalnym krokiem rozwojowym jest implementacja oraz strojenie regulatora PI. Należy dokładniej zwalidować działanie zabezpieczeń oraz dokonać kalibracji odczytów ADC. Należy dokonać korekt w nastawach czasów martwych zgodnie z wykonanymi pomiarami.

Przetwornica wykazuje pełną stabilność sprzętową w trybie napięciowym. Topologia wielofazowa spełniła założenia projektowe redukując tętnienia na wyjściu o ok 80% względem konfiguracji jednofazowej. Rekordowy odczyt sprawności na poziomie 94% przy 8A dowodzi poprawności dobranych elementów mocy.

6. DODATKI


Rysunek 15 Sekcja zasilania pomocniczego


Rysunek 16 Pomocnicza przetwornica obniżająca


Rysunek 17 Sekcja cyfrowa

Rysunek 18 Stopień mocy


Rysunek 19 Sekcja feedback

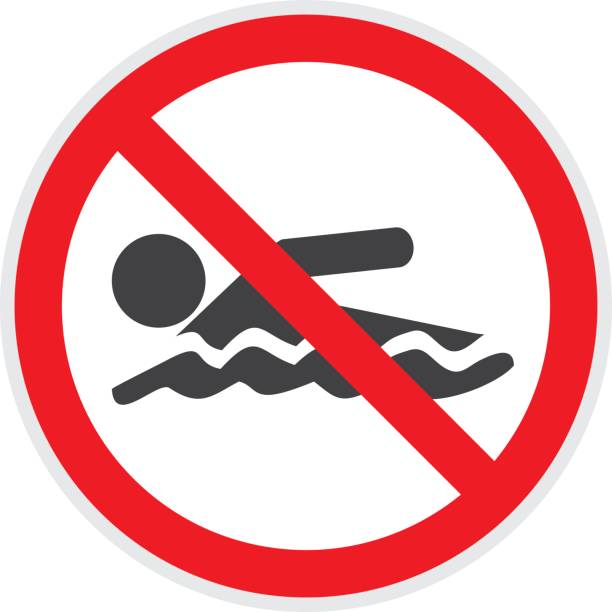
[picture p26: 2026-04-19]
KiCad/MCU_PSU/Pictures/no_swimming.jpg

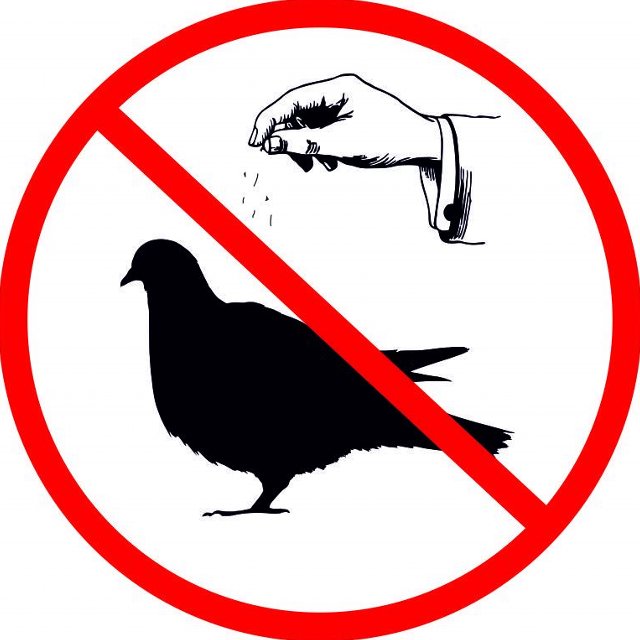
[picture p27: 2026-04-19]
KiCad/MCU_PSU/Pictures/golebie.jpg

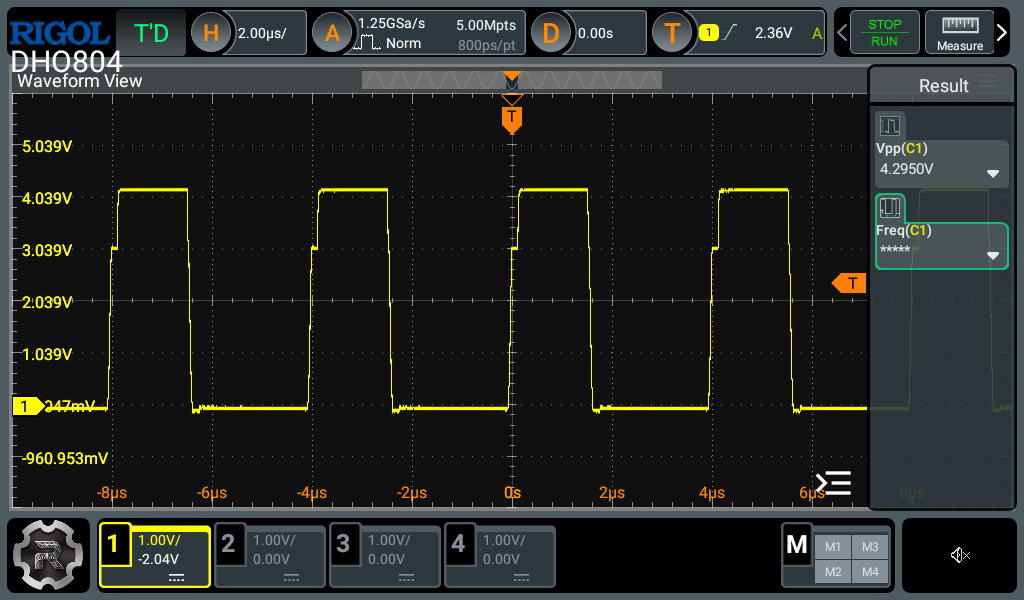
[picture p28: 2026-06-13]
plots/RigolDS10.png

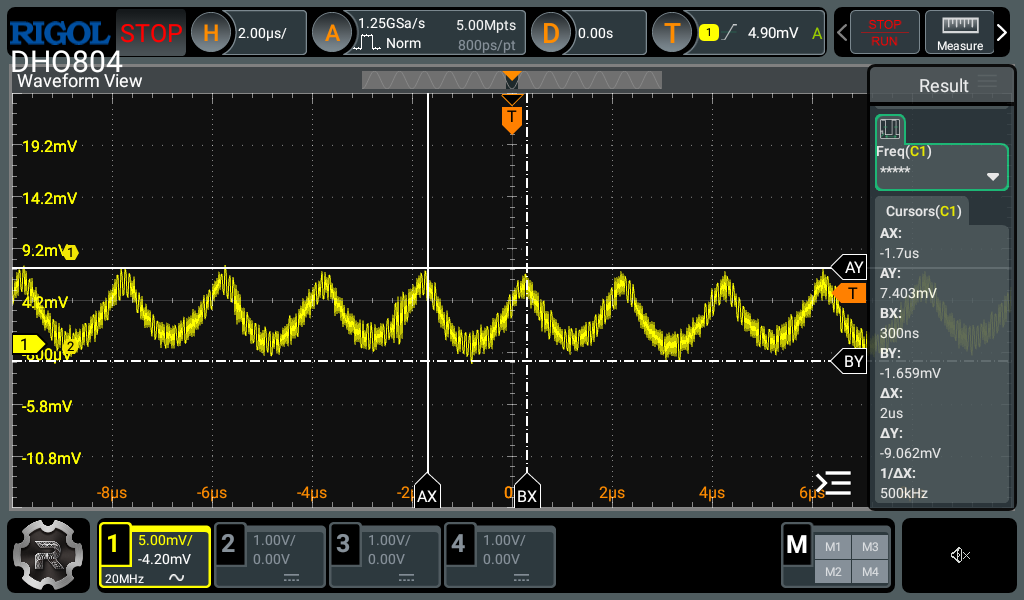
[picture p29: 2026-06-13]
plots/RigolDS8.png

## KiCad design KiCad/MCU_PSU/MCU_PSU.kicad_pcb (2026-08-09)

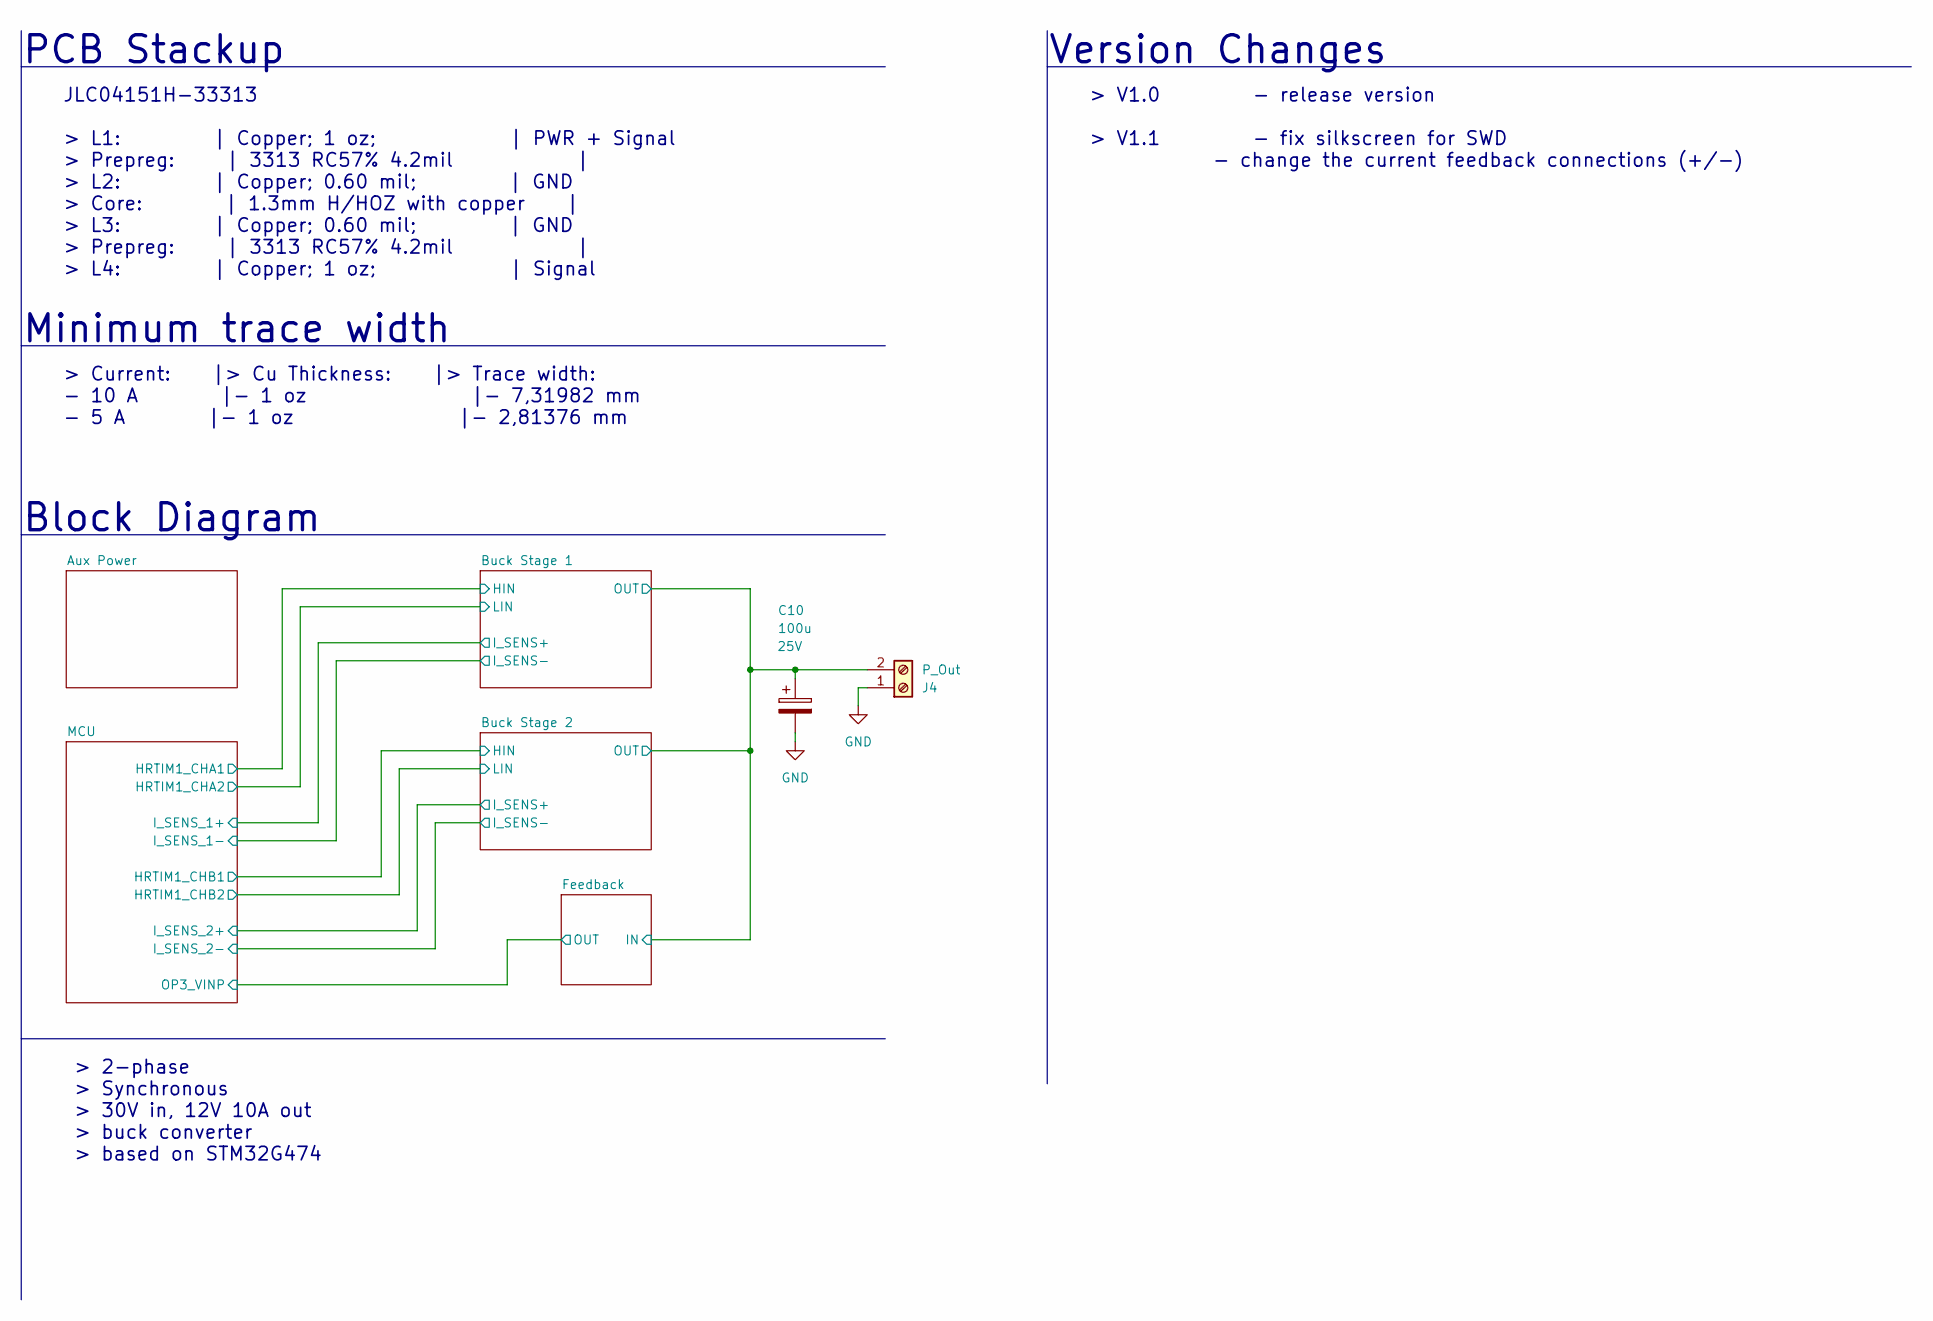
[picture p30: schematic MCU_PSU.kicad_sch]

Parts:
C10: 100u; CP_Elec_8x10.5; Voltage 25V
J4: P_Out; TerminalBlock_Phoenix_PT-1,5-2-5.0-H_1x02_P5.00mm_Horizontal

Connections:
/Buck Stage 1/OUT: C10.1, J4.2; also elsewhere on the board
GND: C10.2, J4.1; also elsewhere on the board

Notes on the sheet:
Minimum trace width
JLC04151H-33313 > L1: | Copper; 1 oz; | PWR + Signal > Prepreg: | 3313 RC57% 4.2mil | > L2: | Copper; 0.60 mil; | GND > Core: | 1.3mm H/HOZ with copper | > L3: | Copper; 0.60 mil; | GND > Prepreg: | 3313 RC57% 4.2mil | > L4: | Copper; 1 oz; | Signal
Block Diagram
> V1.0 - release version > V1.1 - fix silkscreen for SWD - change the current feedback connections (+/-)
> 2-phase > Synchronous > 30V in, 12V 10A out > buck converter > based on STM32G474
Version Changes
> Current: |> Cu Thickness: |> Trace width: - 10 A |- 1 oz |- 7,31982 mm - 5 A |- 1 oz |- 2,81376 mm
PCB Stackup

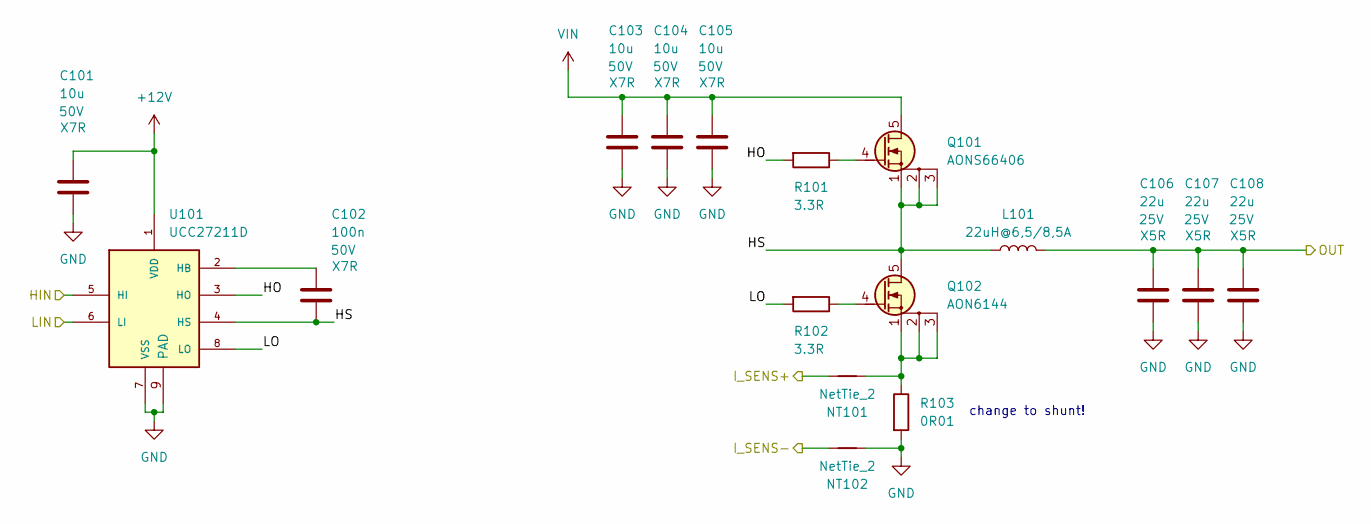
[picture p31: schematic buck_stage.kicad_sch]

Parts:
C101, C103, C104, C105: 10u; C_1206_3216Metric; Voltage 50V
C102: 100n; C_0603_1608Metric; Voltage 50V
C106, C107, C108: 22u; C_0805_2012Metric; Voltage 25V
L101: 22uH@6,5/8,5A; L_Coilcraft_XAL1010-XXX
NT101, NT102: NetTie_2; NetTie-2_SMD_Pad0.5mm
Q101: AONS66406; Infineon_PG-TDSON-8
Q102: AON6144; Infineon_PG-TDSON-8
R101, R102: 3.3R; R_0603_1608Metric_Pad0.98x0.95mm
R103: 0R01; R_1206_3216Metric_Pad1.30x1.75mm
U101: UCC27211D; HTSOP-8-1EP_3.9x4.9mm_P1.27mm_EP2.4x3.2mm_ThermalVias; PARTREV F

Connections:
+12V: C101.1, U101.1 (VDD); also elsewhere on the board
/Buck Stage 1/HIN: U101.5 (HI); also elsewhere on the board
/Buck Stage 1/HO: R101.2, U101.3 (HO)
/Buck Stage 1/HS: C102.2, L101.1, Q101.1 (S), Q101.2 (S), Q101.3 (S), Q102.5 (D), U101.4 (HS)
/Buck Stage 1/I_SENS+: NT101.2; also elsewhere on the board
/Buck Stage 1/I_SENS-: NT102.2; also elsewhere on the board
/Buck Stage 1/LIN: U101.6 (LI); also elsewhere on the board
/Buck Stage 1/LO: R102.2, U101.8 (LO)
/Buck Stage 1/OUT: C106.1, C107.1, C108.1, L101.2; also elsewhere on the board
GND: C101.2, C103.2, C104.2, C105.2, C106.2, C107.2, C108.2, NT102.1, R103.2, U101.7 (VSS), U101.9 (PAD); also elsewhere on the board
unnamed: NT101.1, Q102.1 (S), Q102.2 (S), Q102.3 (S), R103.1
unnamed: Q101.4 (G), R101.1
unnamed: Q102.4 (G), R102.1
unnamed: C102.1, U101.2 (HB)
VIN: C103.1, C104.1, C105.1, Q101.5 (D); also elsewhere on the board

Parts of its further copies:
C201, C203, C204, C205: 10u; C_1206_3216Metric; Voltage 50V
C202: 100n; C_0603_1608Metric; Voltage 50V
C206, C207, C208: 22u; C_0805_2012Metric; Voltage 25V
L201: 22uH@6,5/8,5A; L_Coilcraft_XAL1010-XXX
NT201, NT202: NetTie_2; NetTie-2_SMD_Pad0.5mm
Q201: AONS66406; Infineon_PG-TDSON-8
Q202: AON6144; Infineon_PG-TDSON-8
R201, R202: 3.3R; R_0603_1608Metric_Pad0.98x0.95mm
R203: 0R01; R_1206_3216Metric_Pad1.30x1.75mm
U201: UCC27211D; HTSOP-8-1EP_3.9x4.9mm_P1.27mm_EP2.4x3.2mm_ThermalVias; PARTREV F

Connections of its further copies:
+12V: C201.1, U201.1 (VDD); also elsewhere on the board
/Buck Stage 1/OUT: C206.1, C207.1, C208.1, L201.2; also elsewhere on the board
/Buck Stage 2/HIN: U201.5 (HI); also elsewhere on the board
/Buck Stage 2/HO: R201.2, U201.3 (HO)
/Buck Stage 2/HS: C202.2, L201.1, Q201.1 (S), Q201.2 (S), Q201.3 (S), Q202.5 (D), U201.4 (HS)
/Buck Stage 2/I_SENS+: NT201.2; also elsewhere on the board
/Buck Stage 2/I_SENS-: NT202.2; also elsewhere on the board
/Buck Stage 2/LIN: U201.6 (LI); also elsewhere on the board
/Buck Stage 2/LO: R202.2, U201.8 (LO)
GND: C201.2, C203.2, C204.2, C205.2, C206.2, C207.2, C208.2, NT202.1, R203.2, U201.7 (VSS), U201.9 (PAD); also elsewhere on the board
unnamed: NT201.1, Q202.1 (S), Q202.2 (S), Q202.3 (S), R203.1
unnamed: Q201.4 (G), R201.1
unnamed: Q202.4 (G), R202.1
unnamed: C202.1, U201.2 (HB)
VIN: C203.1, C204.1, C205.1, Q201.5 (D); also elsewhere on the board

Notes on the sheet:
change to shunt!

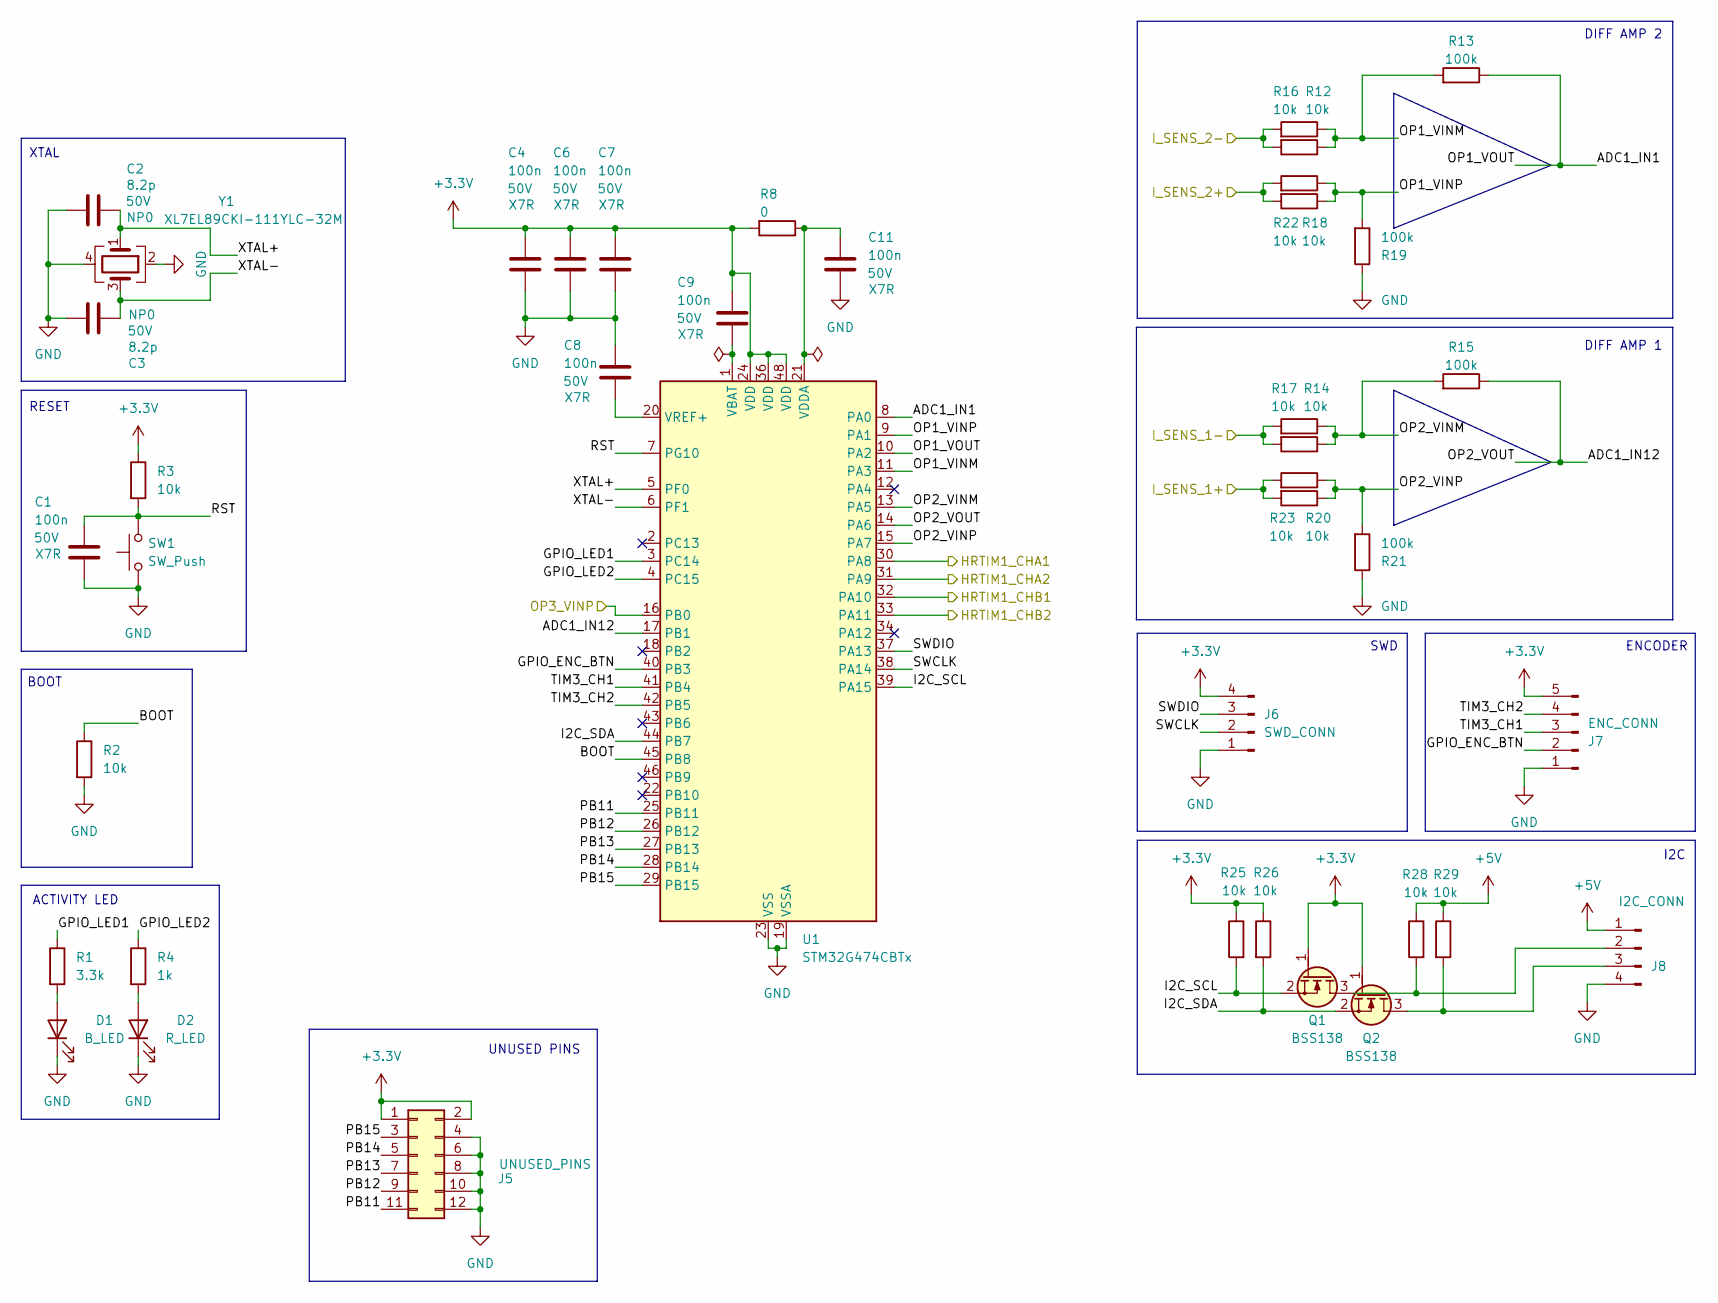
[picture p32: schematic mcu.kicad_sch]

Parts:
C1, C4, C6, C7, C8, C9, C11: 100n; C_0603_1608Metric; Voltage 50V
C2, C3: 8.2p; C_0402_1005Metric; Voltage 50V
D1: B_LED; LED_0603_1608Metric
D2: R_LED; LED_0603_1608Metric
J5: UNUSED_PINS; PinHeader_2x06_P1.27mm_Vertical
J6: SWD_CONN; PinHeader_1x04_P2.54mm_Vertical
J7: ENC_CONN; PinHeader_1x05_P2.54mm_Vertical
J8: I2C_CONN; PinHeader_1x04_P2.54mm_Vertical
Q1, Q2: BSS138; SOT-23
R1: 3.3k; R_0603_1608Metric
R2, R3, R12, R14, R16, R17, R18, R20, R22, R23, R25, R26, R28, R29: 10k; R_0603_1608Metric
R4: 1k; R_0603_1608Metric
R8: 0; R_0603_1608Metric
R13, R15, R19, R21: 100k; R_0603_1608Metric
SW1: SW_Push; SW_PUSH_6mm
U1: STM32G474CBTx; LQFP-48_7x7mm_P0.5mm
Y1: XL7EL89CKI-111YLC-32M; Crystal_SMD_2016-4Pin_2.0x1.6mm

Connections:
+3.3V: C4.1, C6.1, C7.1, C9.1, J5.1, J5.2, J6.4, J7.5, Q1.1 (G), Q2.1 (G), R3.1, R8.2, R25.1, R26.1, U1.24 (VDD), U1.36 (VDD), U1.48 (VDD); also elsewhere on the board
+5V: J8.1, R28.1, R29.1; also elsewhere on the board
/Buck Stage 1/HIN: U1.30 (PA8); also elsewhere on the board
/Buck Stage 1/I_SENS+: R20.2, R23.2; also elsewhere on the board
/Buck Stage 1/I_SENS-: R14.2, R17.2; also elsewhere on the board
/Buck Stage 1/LIN: U1.31 (PA9); also elsewhere on the board
/Buck Stage 2/HIN: U1.32 (PA10); also elsewhere on the board
/Buck Stage 2/I_SENS+: R18.2, R22.2; also elsewhere on the board
/Buck Stage 2/I_SENS-: R12.2, R16.2; also elsewhere on the board
/Buck Stage 2/LIN: U1.33 (PA11); also elsewhere on the board
/Feedback/OUT: U1.16 (PB0); also elsewhere on the board
/MCU/ADC1_IN1: R13.1, U1.8 (PA0), U1.10 (PA2)
/MCU/ADC1_IN12: R15.1, U1.14 (PA6), U1.17 (PB1)
/MCU/BOOT: R2.1, U1.45 (PB8)
/MCU/GPIO_ENC_BTN: J7.2, U1.40 (PB3)
/MCU/GPIO_LED1: R1.1, U1.3 (PC14)
/MCU/GPIO_LED2: R4.1, U1.4 (PC15)
/MCU/I2C_SCL: Q1.2 (S), R25.2, U1.39 (PA15)
/MCU/I2C_SDA: Q2.2 (S), R26.2, U1.44 (PB7)
/MCU/OP1_VINM: R12.1, R13.2, R16.1, U1.11 (PA3)
/MCU/OP1_VINP: R18.1, R19.2, R22.1, U1.9 (PA1)
/MCU/OP2_VINM: R14.1, R15.2, R17.1, U1.13 (PA5)
/MCU/OP2_VINP: R20.1, R21.2, R23.1, U1.15 (PA7)
/MCU/PB11: J5.11, U1.25 (PB11)
/MCU/PB12: J5.9, U1.26 (PB12)
/MCU/PB13: J5.7, U1.27 (PB13)
/MCU/PB14: J5.5, U1.28 (PB14)
/MCU/PB15: J5.3, U1.29 (PB15)
/MCU/RST: C1.1, R3.2, SW1.2, U1.7 (PG10)
/MCU/SWCLK: J6.2, U1.38 (PA14)
/MCU/SWDIO: J6.3, U1.37 (PA13)
/MCU/TIM3_CH1: J7.3, U1.41 (PB4)
/MCU/TIM3_CH2: J7.4, U1.42 (PB5)
/MCU/XTAL+: C2.2, U1.5 (PF0), Y1.1
/MCU/XTAL-: C3.2, U1.6 (PF1), Y1.3
GND: C1.2, C2.1, C3.1, C4.2, C6.2, C7.2, C8.1, C11.2, D1.1 (K), D2.1 (K), J5.4, J5.6, J5.8, J5.10, J5.12, J6.1, J7.1, J8.4, R2.2, R19.1, R21.1, SW1.1, U1.19 (VSSA), U1.23 (VSS), U1.35 (VSS), U1.47 (VSS), Y1.2, Y1.4; also elsewhere on the board
unnamed: D1.2 (A), R1.2
unnamed: D2.2 (A), R4.2
unnamed: J8.2, Q1.3 (D), R28.2
unnamed: J8.3, Q2.3 (D), R29.2
unnamed: C9.2, U1.1 (VBAT)
unnamed: C11.1, R8.1, U1.21 (VDDA)
unnamed: C8.2, U1.20 (VREF+)

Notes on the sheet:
DIFF AMP 1
DIFF AMP 2
ENCODER
UNUSED PINS
BOOT
I2C
XTAL
RESET
ACTIVITY LED
SWD

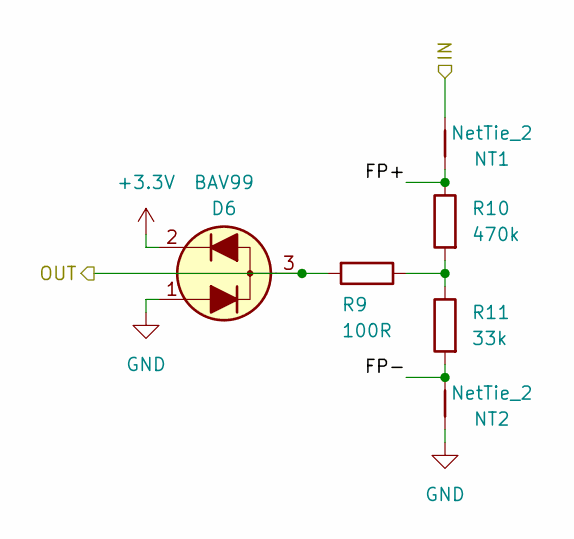
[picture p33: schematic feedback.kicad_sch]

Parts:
D6: BAV99; SOT-23
NT1, NT2: NetTie_2; NetTie-2_SMD_Pad0.5mm
R9: 100R; R_0603_1608Metric
R10: 470k; R_0603_1608Metric
R11: 33k; R_0603_1608Metric

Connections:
+3.3V: D6.2 (K); also elsewhere on the board
/Buck Stage 1/OUT: NT1.2; also elsewhere on the board
/Feedback/FP+: NT1.1, R10.1
/Feedback/FP-: NT2.2, R11.2
/Feedback/OUT: D6.3 (C), R9.2; also elsewhere on the board
GND: D6.1 (A), NT2.1; also elsewhere on the board
unnamed: R9.1, R10.2, R11.1

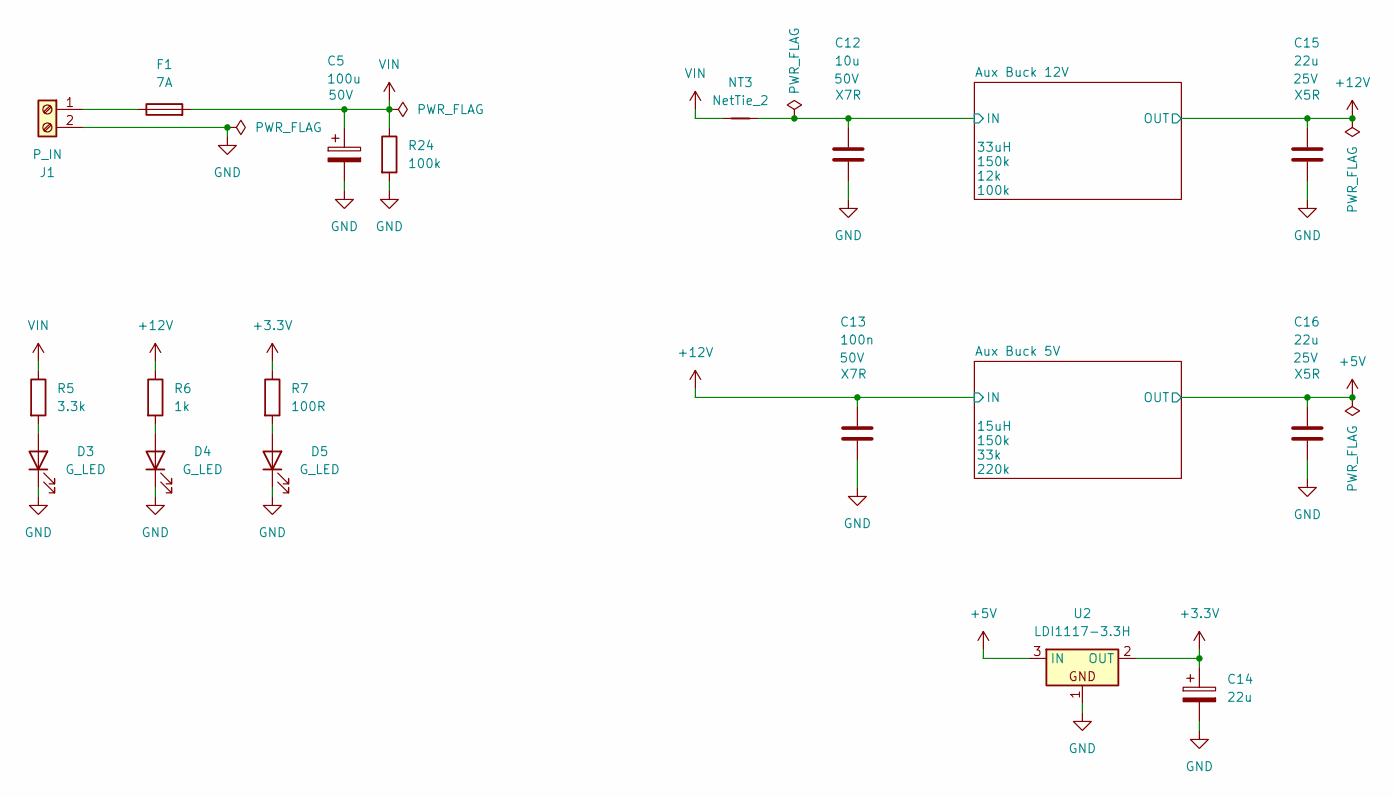
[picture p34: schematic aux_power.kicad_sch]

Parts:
C5: 100u; CP_Elec_8x10.5; Voltage 50V
C12: 10u; C_1206_3216Metric; Voltage 50V
C13: 100n; C_0603_1608Metric; Voltage 50V
C14: 22u; CP_Elec_5x5.4
C15, C16: 22u; C_0805_2012Metric; Voltage 25V
D3, D4, D5: G_LED; LED_0603_1608Metric
F1: 7A; Fuseholder_Clip-5x20mm_Keystone_3517_Inline_P23.11x6.76mm_D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
J1: P_IN; TerminalBlock_Phoenix_PT-1,5-2-5.0-H_1x02_P5.00mm_Horizontal
NT3: NetTie_2; NetTie-2_SMD_Pad0.5mm
R5: 3.3k; R_0603_1608Metric
R6: 1k; R_0603_1608Metric
R7: 100R; R_0603_1608Metric
R24: 100k; R_0603_1608Metric
U2: LDI1117-3.3H; SOT-223-3_TabPin2

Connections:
+3.3V: C14.1, R7.1, U2.2 (OUT); also elsewhere on the board
+5V: C16.1, U2.3 (IN); also elsewhere on the board
+12V: C13.1, C15.1, R6.1; also elsewhere on the board
/Aux Power/Aux Buck 12V/IN: C12.1, NT3.2; also elsewhere on the board
GND: C5.2, C12.2, C13.2, C14.2, C15.2, C16.2, D3.1 (K), D4.1 (K), D5.1 (K), J1.2, R24.2, U2.1; also elsewhere on the board
unnamed: D3.2 (A), R5.2
unnamed: D4.2 (A), R6.2
unnamed: D5.2 (A), R7.2
unnamed: F1.1, J1.1
VIN: C5.1, F1.2, NT3.1, R5.1, R24.1; also elsewhere on the board

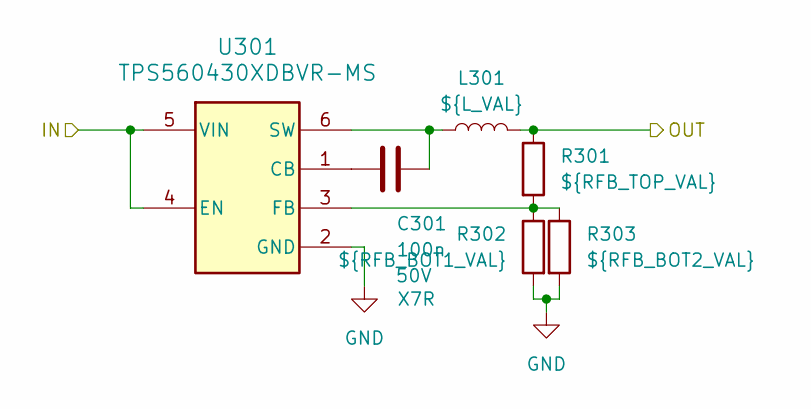
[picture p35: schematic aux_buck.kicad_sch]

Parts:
C301: 100n; C_0603_1608Metric; Voltage 50V
L301: ${L_VAL}; L_Wuerth_MAPI-3015
R301: ${RFB_TOP_VAL}; R_0603_1608Metric
R302: ${RFB_BOT1_VAL}; R_0603_1608Metric
R303: ${RFB_BOT2_VAL}; R_0603_1608Metric
U301: TPS560430XDBVR-MS; SOT-23-6

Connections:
+12V: L301.2, R301.1; also elsewhere on the board
/Aux Power/Aux Buck 12V/IN: U301.4 (EN), U301.5 (VIN); also elsewhere on the board
GND: R302.2, R303.2, U301.2 (GND); also elsewhere on the board
unnamed: C301.1, U301.1 (CB)
unnamed: R301.2, R302.1, R303.1, U301.3 (FB)
unnamed: C301.2, L301.1, U301.6 (SW)

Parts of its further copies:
C401: 100n; C_0603_1608Metric; Voltage 50V
U401: TPS560430XDBVR-MS; SOT-23-6

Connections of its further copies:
+12V: U401.4 (EN), U401.5 (VIN); also elsewhere on the board
GND: U401.2 (GND); also elsewhere on the board
unnamed: C401.1, U401.1 (CB)
unnamed 71: U401.3 (FB); also elsewhere on the board
unnamed 72: C401.2, U401.6 (SW); also elsewhere on the board

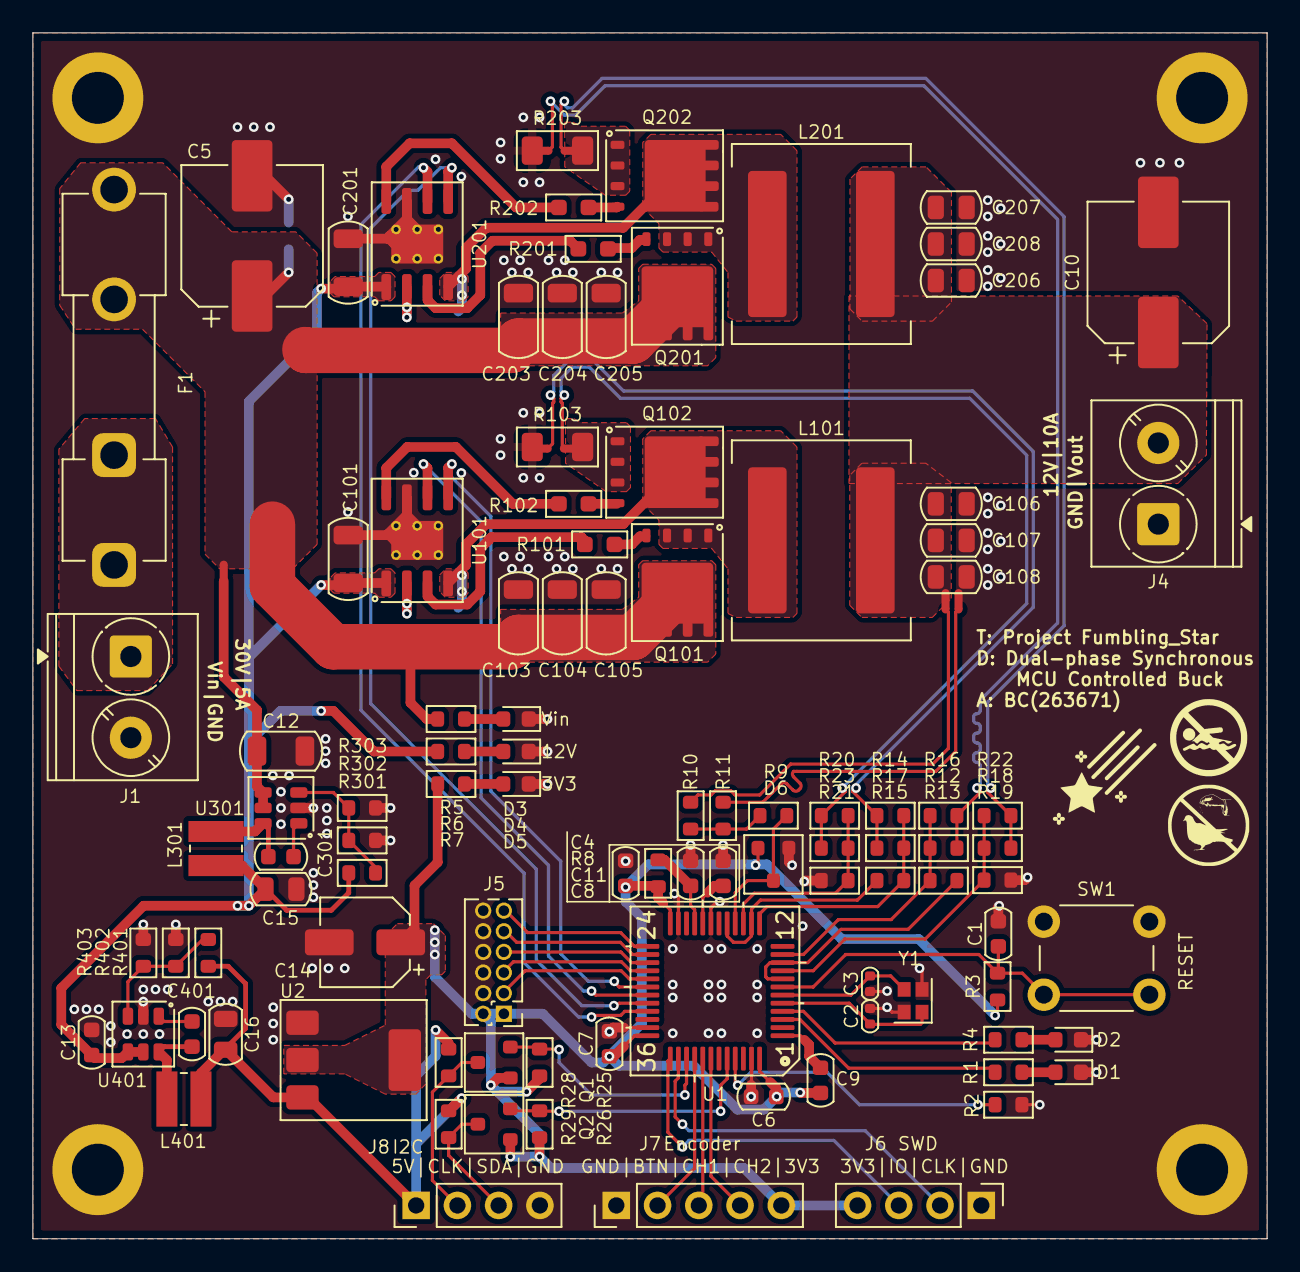
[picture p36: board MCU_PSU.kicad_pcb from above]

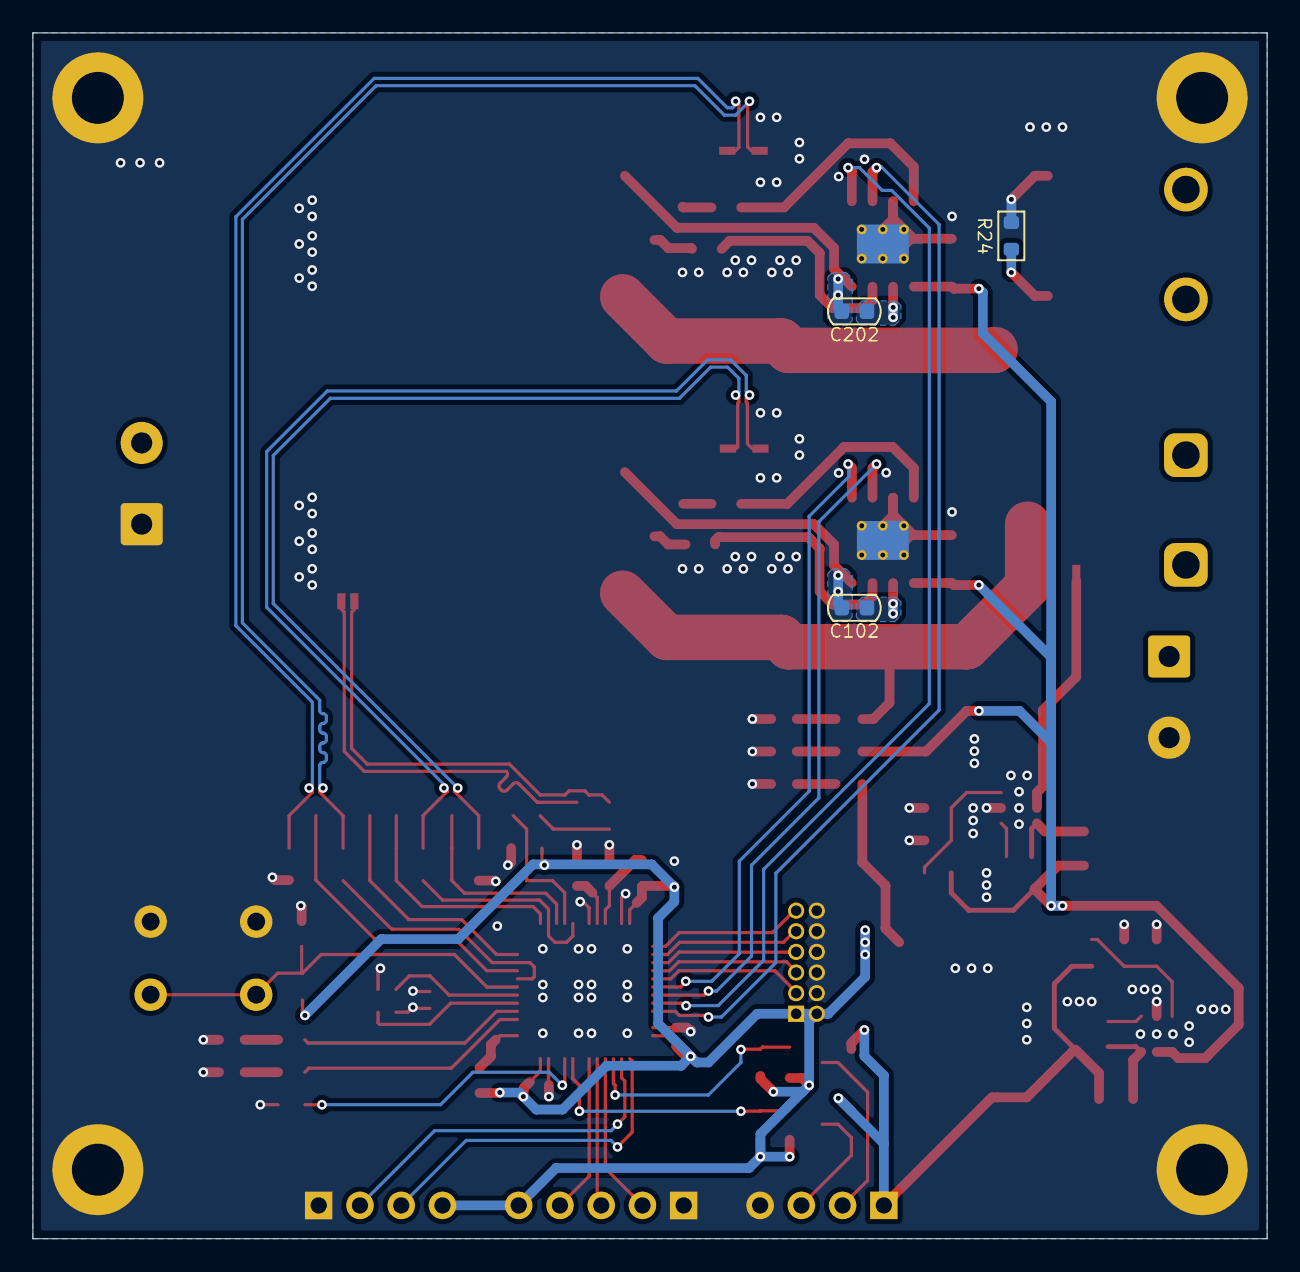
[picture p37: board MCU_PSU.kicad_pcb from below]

Board: 4 copper layers, 76.0 x 74.2 mm, 112 parts (3 on the bottom side), 74 nets.

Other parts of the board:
L401: 15uH; L_Wuerth_MAPI-3015
R401: 150k; R_0603_1608Metric
R402: 33k; R_0603_1608Metric
R403: 220k; R_0603_1608Metric

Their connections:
+5V: L401.2, R401.1; also elsewhere on the board
GND: R402.2, R403.2; also elsewhere on the board
unnamed 71: R401.2, R402.1, R403.1; also elsewhere on the board
unnamed 72: L401.1; also elsewhere on the board

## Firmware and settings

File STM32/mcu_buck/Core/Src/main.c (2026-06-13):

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
/* Includes ------------------------------------------------------------------*/
#include "main.h"

/* USER CODE BEGIN Includes */
#include "I2C_LCD_cfg.h"
/* USER CODE END Includes */

/* USER CODE BEGIN PD */
#define MyI2C_LCD I2C_LCD_1
/* USER CODE END PD */

ADC_HandleTypeDef hadc1;
ADC_HandleTypeDef hadc2;
ADC_HandleTypeDef hadc3;
DMA_HandleTypeDef hdma_adc3;

COMP_HandleTypeDef hcomp1;
COMP_HandleTypeDef hcomp3;

DAC_HandleTypeDef hdac1;
DAC_HandleTypeDef hdac3;

FMAC_HandleTypeDef hfmac;

HRTIM_HandleTypeDef hhrtim1;

I2C_HandleTypeDef hi2c1;

OPAMP_HandleTypeDef hopamp1;
OPAMP_HandleTypeDef hopamp2;
OPAMP_HandleTypeDef hopamp3;

TIM_HandleTypeDef htim3;

/* USER CODE BEGIN PV */
float target_voltage = 12.0f;  // Cel docelowy (zmieniany enkoderem)
float current_voltage = 0.0f;  // Rzeczywiste napięcie, od którego startujemy
float target_current = 1.0f;   // Domyślny limit prądu np. 1.0A
uint8_t edit_mode = 0;         // 0 = Edycja Napięcia, 1 = Edycja Prądu
uint8_t last_btn_state = 1;    // Zakładamy pull-up na przycisku (wewnętrzny lub zewn.)
uint32_t last_update = 0;
uint32_t last_update_ui = 0;
volatile uint32_t new_adc_offset = 0; // Wartość startowa
volatile uint8_t update_offset_flag = 0;
/* USER CODE END PV */

void SystemClock_Config(void);
static void MX_GPIO_Init(void);
static void MX_DMA_Init(void);
static void MX_HRTIM1_Init(void);
static void MX_I2C1_Init(void);
static void MX_OPAMP1_Init(void);
static void MX_OPAMP2_Init(void);
static void MX_ADC1_Init(void);
static void MX_OPAMP3_Init(void);
static void MX_TIM3_Init(void);
static void MX_COMP1_Init(void);
static void MX_DAC1_Init(void);
static void MX_COMP3_Init(void);
static void MX_DAC3_Init(void);
static void MX_ADC3_Init(void);
static void MX_FMAC_Init(void);
static void MX_ADC2_Init(void);
/**
  * @brief  The application entry point.
  * @retval int
  */
int main(void)
{

  /* MCU Configuration--------------------------------------------------------*/

  /* Reset of all peripherals, Initializes the Flash interface and the Systick. */
  HAL_Init();

  /* Configure the system clock */
  SystemClock_Config();

  /* Initialize all configured peripherals */
  MX_GPIO_Init();
  MX_DMA_Init();
  MX_HRTIM1_Init();
  MX_I2C1_Init();
  MX_OPAMP1_Init();
  MX_OPAMP2_Init();
  MX_ADC1_Init();
  MX_OPAMP3_Init();
  MX_TIM3_Init();
  MX_COMP1_Init();
  MX_DAC1_Init();
  MX_COMP3_Init();
  MX_DAC3_Init();
  MX_ADC3_Init();
  MX_FMAC_Init();
  MX_ADC2_Init();
  /* USER CODE BEGIN 2 */

  /* USER CODE BEGIN 2 */

	// --- ZABEZPIECZENIA PRĄDOWE (Hardware Overcurrent Protection) ---

	// 1. Włączamy DAC i ustawiamy próg zadziałania (np. 9.5A -> wartość 3799)
	HAL_DAC_Start(&hdac1, DAC_CHANNEL_1);
	HAL_DAC_SetValue(&hdac1, DAC_CHANNEL_1, DAC_ALIGN_12B_R, 3799); // Próg dla Fazy 1 (COMP3)

	HAL_DAC_Start(&hdac3, DAC_CHANNEL_1);
	HAL_DAC_SetValue(&hdac3, DAC_CHANNEL_1, DAC_ALIGN_12B_R, 3799); // Próg dla Fazy 2 (COMP1)

	// 2. Włączamy komparatory
	HAL_COMP_Start(&hcomp1); // Faza 2
	HAL_COMP_Start(&hcomp3); // Faza 1



////////////////////////////////////////////////////////////////////////////////////////////////////////////////////////////////////////////////

    // 1. WŁĄCZENIE OPAMP (Bufor napięcia sprzężenia zwrotnego - OPAMP3)
    HAL_OPAMP_Start(&hopamp3);


    // Opcjonalnie włącz od razu tory prądowe na przyszłość
    // HAL_OPAMP_Start(&hopamp1);
    // HAL_OPAMP_Start(&hopamp2);

    // 2. KONFIGURACJA WSPÓŁCZYNNIKÓW FMAC (Regulator PI)
    FMAC_FilterConfigTypeDef sFmacConfig = {0};

//    int16_t a_coefs[2] = { 32767, 0 };
//    int16_t b_coefs[3] = { -0x0100, 0x00F0, 0 };

	int16_t a_coefs[2] = { 0, 0 };
	int16_t b_coefs[3] = { -32768, 0, 0 };

    sFmacConfig.CoeffBaseAddress = 0;
    sFmacConfig.CoeffBufferSize = 5;
    sFmacConfig.InputBaseAddress = 5;
    sFmacConfig.InputBufferSize = 3;
    sFmacConfig.InputThreshold = FMAC_THRESHOLD_1;
    sFmacConfig.OutputBaseAddress = 8;
    sFmacConfig.OutputBufferSize = 3;
    sFmacConfig.OutputThreshold = FMAC_THRESHOLD_1;

    sFmacConfig.P = 3; // Liczba współczynników B
    sFmacConfig.Q = 2; // Liczba współczynników A

    sFmacConfig.pCoeffA = a_coefs;
    sFmacConfig.CoeffASize = 2;
    sFmacConfig.pCoeffB = b_coefs;
    sFmacConfig.CoeffBSize = 3;

    sFmacConfig.Filter = FMAC_FUNC_IIR_DIRECT_FORM_1;
    sFmacConfig.InputAccess = FMAC_BUFFER_ACCESS_DMA;  // Wejście zasila DMA z ADC
    sFmacConfig.OutputAccess = FMAC_BUFFER_ACCESS_IT;  // Wyjście generuje Przerwanie

    // Załadowanie konfiguracji
	if (HAL_FMAC_FilterConfig(&hfmac, &sFmacConfig) != HAL_OK)
	{
		Error_Handler();
	}

    HAL_NVIC_SetPriority(FMAC_IRQn, 0, 0); // Ustaw odpowiedni priorytet
    HAL_NVIC_EnableIRQ(FMAC_IRQn);

    // KRYTYCZNE: Start FMAC zgodnie z AN5305 przy użyciu zmiennych-atrap
	uint16_t dummy_expected_size = 1;
	int16_t dummy_output;

	// Ta funkcja złoży do końca rejestr PARAM i włączy bit START
	if (HAL_FMAC_FilterStart(&hfmac, &dummy_output, &dummy_expected_size) != HAL_OK)
	{
		Error_Handler();
	}

	// Następnie kalibrujemy ADC i puszczamy DMA
	HAL_SYSCFG_VREFBUF_VoltageScalingConfig(SYSCFG_VREFBUF_VOLTAGE_SCALE0);
	HAL_SYSCFG_EnableVREFBUF();

	HAL_ADCEx_Calibration_Start(&hadc3, ADC_SINGLE_ENDED);
	HAL_ADC_Start_DMA(&hadc3, (uint32_t *)&FMAC->WDATA, 1);
	// ZABIJA MORDERCZE PRZERWANIA DMA WŁĄCZONE PRZEZ HAL!
	__HAL_DMA_DISABLE_IT(&hdma_adc3, DMA_IT_TC | DMA_IT_HT | DMA_IT_TE);
	// Na wszelki wypadek upewniamy się, że ADC też nas nie męczy
	__HAL_ADC_DISABLE_IT(&hadc3, ADC_IT_OVR | ADC_IT_EOC | ADC_IT_EOS);

	// Uruchomienie pomiarów prądu (bez DMA i Przerwań - w trybie continuous na żądanie sprzętowe)
	HAL_ADCEx_Calibration_Start(&hadc2, ADC_SINGLE_ENDED);
	HAL_ADCEx_Calibration_Start(&hadc1, ADC_SINGLE_ENDED);
	HAL_ADC_Start(&hadc2); // Faza 1 (Wyzwala TRG5 / CMP4)
	HAL_ADC_Start(&hadc1); // Faza 2 (Wyzwala TRG1 / CMP3)
    HAL_OPAMP_Start(&hopamp1);
    HAL_OPAMP_Start(&hopamp2);

	/////////////////////////////////////////////////////////////////////

    //UI

	HAL_TIM_Encoder_Start(&htim3, TIM_CHANNEL_ALL);

	//HAL_I2C_Init(&hi2c1);
	MX_I2C1_Init();

	I2C_LCD_Init(MyI2C_LCD);
	I2C_LCD_Clear(MyI2C_LCD);
	I2C_LCD_Backlight(MyI2C_LCD);
	I2C_LCD_NoBacklight(MyI2C_LCD);
	I2C_LCD_Backlight(MyI2C_LCD);

	////////////////////////////////////////////////////////////////////////////////////////////////////

    uint32_t T_PERIOD = 21760;
    float DUTY = 0.0f;

    // 1. Obliczenie czasu ON
    uint32_t T_COMP_TON = (uint32_t)(((float)T_PERIOD * DUTY) + 0.5f);

    // 2. Przesunięcie fazowe o 180 stopni (w połowie okresu Mastera) - 10880 ticks
    uint32_t T_MASTER_PHASE_SHIFT = T_PERIOD / 2;

    // === FAZA A (Timer A) ===
    // Włącza się na początku okresu (0), wyłącza przy T_COMP_TON
    __HAL_HRTIM_SETCOMPARE(&hhrtim1, HRTIM_TIMERINDEX_TIMER_A, HRTIM_COMPAREUNIT_1, T_COMP_TON);

    // === FAZA B (Timer B) ===
    // Ponieważ liczniki bazy czasu są zsynchronizowane, Faza B włącza się przy 10880.
    // Aby trwała tyle samo co Faza A, musi się wyłączyć przy: 10880 + 8704 = 19584
    uint32_t T_COMP_TIMB_RESET = T_MASTER_PHASE_SHIFT + T_COMP_TON;
    __HAL_HRTIM_SETCOMPARE(&hhrtim1, HRTIM_TIMERINDEX_TIMER_B, HRTIM_COMPAREUNIT_1, T_COMP_TIMB_RESET);

    // === POMIARY ADC (Wyznaczenie środka czasu TOFF dla prądu średniego) ===
    uint32_t T_HALF_TOFF = (T_PERIOD - T_COMP_TON) / 2; // Połowa czasu OFF (6528 ticks)
    __HAL_HRTIM_SETCOMPARE(&hhrtim1, HRTIM_TIMERINDEX_TIMER_A, HRTIM_COMPAREUNIT_3, T_COMP_TON + T_HALF_TOFF);	// Dla Fazy A: Środek TOFF wypada w punkcie TON + (TOFF / 2)

    uint32_t T_TIMB_ADC_TRIG = (T_COMP_TIMB_RESET + T_HALF_TOFF) % T_PERIOD;
    __HAL_HRTIM_SETCOMPARE(&hhrtim1, HRTIM_TIMERINDEX_TIMER_B, HRTIM_COMPAREUNIT_4, T_TIMB_ADC_TRIG); // Dla Fazy B: Środek TOFF wypada w punkcie RESET_B + (TOFF / 2).
    // Używamy modulo (%), ponieważ punkt ten może przekroczyć okres i zawinąć się na początek

    // 3. Włączenie wyjść fizycznych HRTIM (TA1, TA2, TB1, TB2)
    HAL_HRTIM_WaveformOutputStart(&hhrtim1, HRTIM_OUTPUT_TA1 | HRTIM_OUTPUT_TA2 | HRTIM_OUTPUT_TB1 | HRTIM_OUTPUT_TB2);

    // 4. Start liczników za pomocą poprawnych masek bitowych (ID)!
    HAL_HRTIM_WaveformCounterStart(&hhrtim1, HRTIM_TIMERID_MASTER | HRTIM_TIMERID_TIMER_A | HRTIM_TIMERID_TIMER_B);



  /* USER CODE END 2 */

  /* Infinite loop */
  /* USER CODE BEGIN WHILE */
  while (1)
  {
    /* USER CODE END WHILE */

    /* USER CODE BEGIN 3 */

//	// 1. Odczyt Enkodera (bez opóźnień)
//	// Rzutujemy na int16_t, żeby poprawnie obsłużyć kręcenie w lewo (wartości ujemne)
//	int16_t encoder_delta = (int16_t)__HAL_TIM_GET_COUNTER(&htim3);
//
//	if (encoder_delta != 0)
//	{
//		__HAL_TIM_SET_COUNTER(&htim3, 0); // Reset delty
//
//		// Zmiana o 0.1V na każdy "ząbek" enkodera
//		target_voltage += (float)encoder_delta * 0.1f;
//
//		// Limity dla bezpieczeństwa (np. od 2V do 24V)
//		if (target_voltage < 2.0f) target_voltage = 2.0f;
//		if (target_voltage > 24.0f) target_voltage = 24.0f;
//
//		// Przeliczenie na wartość dla rejestru OFFSET ADC
//		// V_pin = target_voltage * (33.0 / 503.0)
//		// Wartość 12-bit = (V_pin / 2.048) * 4096
//		float v_pin = target_voltage * (33.0f / 503.0f);
//		uint32_t adc_val = (uint32_t)((v_pin / 2.048f) * 4096.0f);
//
//		// Ograniczenie dla 12 bitów
//		if(adc_val > 4095) adc_val = 4095;
//
//		// Przekazanie nowych nastaw do bezpiecznego załadowania w przerwaniu
//		new_adc_offset = adc_val;
//		update_offset_flag = 1;
//	}

	if (HAL_GetTick() - last_update >= 10)  // Sprawdzamy co np. 50 ms
	{
		last_update = HAL_GetTick();
		//HAL_GPIO_TogglePin(GPIOC, GPIO_PIN_14); //Dioda sygalizująca start programu

		// 1. SOFT-START (Rampa napięciowa)
		if (current_voltage < target_voltage) {
		  current_voltage += 0.1f; // Prędkość narastania: 0.1V co 50ms = 2V na sekundę
		  if (current_voltage > target_voltage) current_voltage = target_voltage;
		}
		else if (current_voltage > target_voltage) {
		  current_voltage -= 0.1f; // Płynne opadanie przy zmniejszaniu nastawy
		  if (current_voltage < target_voltage) current_voltage = target_voltage;
		}

		// 2. Kalkulacja offsetu na podstawie CURRENT_VOLTAGE (a nie target)
		float v_pin = current_voltage * (33.0f / 503.0f);
		uint32_t adc_val = (uint32_t)((v_pin / 2.048f) * 4096.0f);
		if(adc_val > 4095) adc_val = 4095;

		// 3. Wysłanie flagi do aktualizacji w przerwaniu
		new_adc_offset = adc_val;
		update_offset_flag = 1;
	}

  if (HAL_GetTick() - last_update_ui >= 100)
  {
		last_update_ui = HAL_GetTick();

		// =================================================================
		// 1. OBSŁUGA PRZYCISKU ENKODERA (PB3) Z PROSTYM DEBOUNCE
		// =================================================================
		uint8_t btn_state = HAL_GPIO_ReadPin(GPIOB, GPIO_PIN_3);

		// Wykrywamy wciśnięcie (zbocze opadające na pull-upie)
		if (btn_state == GPIO_PIN_RESET && last_btn_state == GPIO_PIN_SET)
		{
			edit_mode = !edit_mode; // Przełącz: 0 (Napięcie) <-> 1 (Prąd)
			I2C_LCD_Clear(I2C_LCD_1); // Czyścimy ekran przy zmianie trybu, żeby usunąć stary wskaźnik ">"
		}
		last_btn_state = btn_state;

		// =================================================================
		// 2. ODCZYT ENKODERA I AKTUALIZACJA NASTAW
		// =================================================================
		int16_t encoder_delta = (int16_t)__HAL_TIM_GET_COUNTER(&htim3);

		if (encoder_delta != 0)
		{
			__HAL_TIM_SET_COUNTER(&htim3, 0); // Reset licznika hardware'owego

			if (edit_mode == 0)
			{
				// --- TRYB CV: Edycja Napięcia ---
				target_voltage += (float)encoder_delta * 0.1f; // Krok o 0.1V
				if (target_voltage < 1.0f)  target_voltage = 1.0f;
				if (target_voltage > 24.0f) target_voltage = 24.0f;

				// Przeliczenie na wartość dla rejestru OFFSET ADC
				// V_pin = target_voltage * (33.0 / 503.0)
				// Wartość 12-bit = (V_pin / 2.048) * 4096
				float v_pin = target_voltage * (33.0f / 503.0f);
				uint32_t adc_val = (uint32_t)((v_pin / 2.048f) * 4096.0f);

				// Ograniczenie dla 12 bitów
				if(adc_val > 4095) adc_val = 4095;

				// Przekazanie nowych nastaw do bezpiecznego załadowania w przerwaniu
				new_adc_offset = adc_val;
				update_offset_flag = 1;
			}
			else
			{
				// --- TRYB CC ("Bieda CC"): Edycja Limitu Prądu ---
				target_current += (float)encoder_delta * 0.1f; // Krok o 0.1A
				if (target_current < 0.2f)  target_current = 0.2f;
				if (target_current > 10.0f) target_current = 10.0f;

				// Przesterowanie DAC-ów dla komparatorów (Valley Current Limit)
				// Zakładamy: Bocznik 10 mOhm, Wzmocnienie OpAmp = 20, VREF = 2.048V
				float v_opamp = target_current * 0.01f * 20.0f;
				uint32_t dac_val = (uint32_t)((v_opamp / 2.048f) * 4096.0f);
				if (dac_val > 4095) dac_val = 4095;

				// Wpisujemy próg bezpośrednio do rejestrów DAC dla obu faz
				HAL_DAC_SetValue(&hdac1, DAC_CHANNEL_1, DAC_ALIGN_12B_R, dac_val);
				HAL_DAC_SetValue(&hdac3, DAC_CHANNEL_1, DAC_ALIGN_12B_R, dac_val);
			}
		}

		// =================================================================
		// 3. SPYTNA RESTRUKTURYZACJA SPRINTF (BEZ FLOATA) I WYŚWIETLANIE
		// =================================================================
		char lcd_buf[17]; // Bufor na jedną linię (16 znaków + '\0')

		// Rozbijamy Floaty na Integery (Szybkie i bezpieczne dla pamięci)
		uint16_t v_whole = (uint16_t)target_voltage;
		uint16_t v_frac  = (uint16_t)((target_voltage - (float)v_whole) * 10.0f + 0.5f); // +0.5 zapobiega błędom zaokrągleń floatów
		if (v_frac >= 10) { v_frac = 0; v_whole++; }

		uint16_t i_whole = (uint16_t)target_current;
		uint16_t i_frac  = (uint16_t)((target_current - (float)i_whole) * 10.0f + 0.5f);
		if (i_frac >= 10) { i_frac = 0; i_whole++; }

		// --- LINIA 1: Napięcie Zadane ---
		// Znak '>' ląduje po lewej stronie, jeśli edit_mode == 0
		sprintf(lcd_buf, "%c V_Set: %2u.%1uV ", (edit_mode == 0) ? '>' : ' ', v_whole, v_frac);
		I2C_LCD_SetCursor(MyI2C_LCD, 0, 0); // Kolumna 0, Wiersz 0
		I2C_LCD_WriteString(MyI2C_LCD, lcd_buf);

		// --- LINIA 2: Prąd Zadany (Limit DAC) ---
		// Znak '>' ląduje po lewej stronie, jeśli edit_mode == 1
		sprintf(lcd_buf, "%c I_Lim: %2u.%1uA ", (edit_mode == 1) ? '>' : ' ', i_whole, i_frac);
		I2C_LCD_SetCursor(MyI2C_LCD, 0, 1); // Kolumna 0, Wiersz 1
		I2C_LCD_WriteString(MyI2C_LCD, lcd_buf);

		// Migamy diodą diagnostyczną pętli głównej
		HAL_GPIO_TogglePin(GPIOC, GPIO_PIN_14);
	  }
  }
  /* USER CODE END 3 */
}

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


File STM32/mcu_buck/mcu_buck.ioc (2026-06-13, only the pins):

Mcu.UserName=STM32G474CBTx
PA0.Signal=SharedAnalog_PA0
PA1.Signal=OPAMP1_VINP
PA10.Signal=HRTIM1_CHB1
PA11.Signal=HRTIM1_CHB2
PA13.Signal=SYS_JTMS-SWDIO
PA14.Signal=SYS_JTCK-SWCLK
PA15.Signal=I2C1_SCL
PA2.Signal=OPAMP1_VOUT
PA3.Signal=OPAMP1_VINM
PA5.Signal=OPAMP2_VINM
PA6.Signal=OPAMP2_VOUT
PA7.Signal=OPAMP2_VINP
PA8.Signal=HRTIM1_CHA1
PA9.Signal=HRTIM1_CHA2
PB0.Signal=OPAMP3_VINP
PB1.Signal=SharedAnalog_PB1
PB3.Signal=GPIO_Input
PB4.Signal=S_TIM3_CH1
PB5.Signal=S_TIM3_CH2
PB7.Signal=I2C1_SDA
PC14-OSC32_IN.Signal=GPIO_Output
PC15-OSC32_OUT.Signal=GPIO_Output
PF0-OSC_IN.Signal=RCC_OSC_IN
PF1-OSC_OUT.Signal=RCC_OSC_OUT

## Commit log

2026-04-10 board, mcu pinout
    [MCU_PSU.kicad_pcb, MCU_PSU.kicad_sch, aux_buck.kicad_sch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]
2026-04-19 removed reserved pin connectors, changed MCU pin definitions, added comparators to adc pins for current control scheme, refined mcu layout
    [MCU_PSU.kicad_pcb, aux_power.kicad_sch, mcu.kicad_sch]
2026-04-19 added silkscreen descriptions and art
    [MCU_PSU.kicad_pcb, MCU_PSU.kicad_sch]
2026-06-04 voltage feedback working, implemented not tested (phase balancing, encoder settings, ocp)
    [MCU_PSU.kicad_pcb, aux_buck.kicad_sch, aux_power.kicad_sch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]
2026-06-06 Add encoder-based voltage control & HRTIM tweaks
    Introduce encoder-driven target_voltage/current_voltage with soft-start and safe ADC offset updates. Add new globals (new_adc_offset, update_offset_flag, last_update) and poll TIM3 encoder to compute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
2026-06-13 Add I2C LCD driver and UI/Util updates
    Add an I2C LCD driver and supporting files (Core/Inc I2C_LCD.h, I2C_LCD_cfg.h, Util.h and Core/Src I2C_LCD.c, I2C_LCD_cfg.c, Util.c) and a default LCD configuration (0x27, 16x2). Integrate LCD and si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
    [Sprawnosc.xlsx]
2026-08-08 Add README for 2-Phase Buck Converter project
    Added comprehensive documentation for the 2-Phase Synchronous Digitally Controlled Buck Converter project, covering project overview, system architecture, hardware details, control loop architecture,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
2026-08-09 fix silkscreen, current feedback, shunt thermal connection
    [MCU_PSU.kicad_pcb, MCU_PSU.kicad_sch, buck_stage.kicad_sch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]

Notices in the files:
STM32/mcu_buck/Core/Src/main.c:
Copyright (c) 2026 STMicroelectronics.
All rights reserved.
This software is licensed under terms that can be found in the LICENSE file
